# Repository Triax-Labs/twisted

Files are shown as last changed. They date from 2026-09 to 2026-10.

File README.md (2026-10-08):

<p align="center">
  
</p>
<h1 align="center">Twisted</h1>

Twisted is a tiny (14x32mm to be precise) ESP32-S3 based platform, which has dual Xtensa LX7 cores, 4Mb of flash, 2Mb of PSRAM, 512Kb of SRAM as well as BLE and WiFi on board, paired with an [0.42" IPS LCD](https://www.buydisplay.com/0-42-inch-mini-color-tft-lcd-display-module-96x54-ips-st7735), a keypad, a Neopixel and built-in battery management with USB OTG.




pcb layer by layer view

There is one more thing, the platform is extendable! It features a 20 pin 1.27mm expansion header which allows you of attaching other boards that add extra features, giving _Twisted_ a reason for its name.

We currently have three expansion boards for Twisted...

## Twisted Listen

An audio codec based on ES8316, which provides a high performance DAC and ADC, the attachment comes with both a builtin microphone and amplifier for a loudspeaker, as well as a 3.5mm headphone jack (with microphone in.)




pcb layer by layer view

## Twisted Connect

A shield for the Twisted Bus that provides the functionality of an extra microcontroller, it adds on a CH585 MCU which comes with an interesting set of peripherals, NFC/RFID (with support for reading, writing and emulating tags,) both a USB High Speed and a USB Full Speed controller as well as a BLE / 2.4GHz modem.

Twisted Connect could be used for using the peripherals on the CH585 MCU alongside the ESP32-S3 on the main Twisted board or it could be used to deep sleep the ESP32-S3 to preserve power, since Twisted Connect could take over the bus, it can wake up the ESP32-S3 when a trigger happens (e.g. sensors over I2C or a BLE/USB packet.)




pcb layer by layer view

## Twisted Sense (WIP)

An attachment that provides a a suite of sensors and trackers (pressure, temperature, humidity, gyroscope, accelerometer, magnetometer and GPS/GNSS) aiming to help the device "feel" what happens around it.

## Production

Production could be done through [JLCPCB](https://jlcpcb.com)'s PCBA service.

Total _(estimated)_ costs for Twisted boards (does not include any of the extra shields):

| Item | Price | Qty | Where |
| ---- | ----- | --- | --- |
| PCB  | $7 | 5 Boards | [JLCPCB](https://jlcpcb.com) |
| PCBA | $100  | 5 Boards | [JLCPCB](https://jlcpcb.com) |

You will need to assemble one side of the board, the other side which has the display, a resistor and the keypad you will have to assemble it yourself, or let JLCPCB assemble it for you at a higher cost.

You will need the display to be sourced and assembled by yourself, this is where you can buy it:

- AliExpress: [listing](https://aliexpress.com/item/1005007804650049.html) / [listing](https://aliexpress.com/item/1005008528322628.html) / [listing](https://aliexpress.com/item/1005012246832580.html) / [listing](https://aliexpress.com/item/1005008885821582.html)
- [BuyDisplay](https://www.buydisplay.com/0-42-inch-mini-color-tft-lcd-display-module-96x54-ips-st7735)

If you decide to buy the display from a different supplier, make sure it comes with a 16 pin flex cable, it also has to follow this pinout:


Total _(estimated)_ costs for Twisted Listen boards:

| Item | Price | Qty | Where |
| ---- | ----- | --- | --- |
| PCB  | $7 | 5 Boards | [JLCPCB](https://jlcpcb.com) |
| PCBA | $60 | 5 Boards | [JLCPCB](https://jlcpcb.com) |

Total _(estimated)_ costs for a Twisted Connect boards:

| Item | Price | Qty | Where |
| ---- | ----- | --- | --- |
| PCB  | $7 | 5 Boards | [JLCPCB](https://jlcpcb.com) |
| PCBA | $80 | 5 Boards | [JLCPCB](https://jlcpcb.com) |

_Note that these tables don't include shipping charges._

Production files could be found in `/hardware/X/production`.

## GPIO Pins Mapping (Twisted Bus)

| GPIO | Strap | ADC | HWSPI | Remark | Exposed | On Twisted |
| :--: | :---: | :---: | :---: | --- | :---: | --- |
|  0 |  Yes  | | | Pull LOW to Enter BOOT | No | Boot Button |
|  1 |  No | ADC1 CH0 | | | Yes | Expansion Header  |
|  2 |  No | ADC1 CH1 | | | Yes | Expansion Header  |
|  3 |  Yes  | ADC1 CH2 | | Pull LOW to Use An External Debugger Instead of USB | Yes | Expansion Header  |
|  4 |  No | ADC1 CH3 | | | Yes | Expansion Header  |
|  5 |  No | ADC1 CH4 | | | Yes | Expansion Header  |
|  6 |  No | ADC1 CH5 | | | Yes | Expansion Header  |
|  7 |  No | ADC1 CH6 | | | Yes | Expansion Header  |
|  8 |  No | ADC1 CH7 | | | Yes | Expansion Header  |
|  9 |  No | ADC1 CH8 | Hold  | | Yes | Expansion Header  |
|  10  |  No | ADC1 CH9 |  CS | | Yes | Expansion Header  |
|  11  |  No | ADC2 CH0 | MOSI  | | Yes | Expansion Header  |
|  12  |  No | ADC2 CH1 |  SCK  | | Yes | Expansion Header  |
|  13  |  No | ADC2 CH2 | MISO  | | Yes | Expansion Header  |
|  14  |  No | ADC2 CH3 |  WP | | Yes | Expansion Header  |
|  15  |  No | ADC2 CH4 | | | Yes | Expansion Header  |
|  16  |  No | ADC2 CH5 | | | Yes | Expansion Header  |
|  17  |  No | ADC2 CH6 | | | Yes | Expansion Header  |
|  18  |  No | ADC2 CH7 | | | No | Keypad: INT |
|  19  |  Yes  | ADC2 CH8 | | USB D- | Yes | USB Port |
|  20  |  Yes  | ADC2 CH9 | | USB D+ | Yes | USB Port |
|  21  |  No | | | | No | Neopixel: DIN |
|  26  |  Yes  | | | Used for QSPI Flash/PSRAM | No | Unused |
|  27  |  Yes  | | | Used for QSPI Flash/PSRAM | No | Unused |
|  28  |  Yes  | | | Used for QSPI Flash/PSRAM | No | Unused |
|  29  |  Yes  | | | Used for QSPI Flash/PSRAM | No | Unused |
|  30  |  Yes  | | | Used for QSPI Flash/PSRAM | No | Unused |
|  31  |  Yes  | | | Used for QSPI Flash/PSRAM | No | Unused |
|  32  |  Yes  | | | Used for QSPI Flash/PSRAM | No | Unused |
|  33  | Maybe | | | Straps for Chips w/ Octal-SPI PSRAM | No | LCD: RST |
|  34  | Maybe | | | Straps for Chips w/ Octal-SPI PSRAM | No | LCD: SCK |
|  35  | Maybe | | | Straps for Chips w/ Octal-SPI PSRAM | No | LCD: CS |
|  36  | Maybe | | | Straps for Chips w/ Octal-SPI PSRAM | No | LCD: MOSI |
|  37  | Maybe | | | Straps for Chips w/ Octal-SPI PSRAM | No | LCD: BKL |
|  38  |  No | | | | No | Unused |
|  39  |  No | | | | No | Keypad: RST |
|  40  |  No | | | | No | Unused |
|  41  |  No | | | | Through Testpoint | Internal I2C: SDA |
|  42  |  No | | | | Through Testpoint | Internal I2C: SDA |
|  43  |  No | | | Default UART: TX | Through Testpoint | Unused |
|  44  |  No | | | Default UART: RX | Through Testpoint | Unused |
|  45  |  Yes  | | | | No | Unused |
|  46  |  Yes  | | | | No | Unused |
|  47  |  No | | | | No | LCD: DC |
|  48  |  No | | | | No | BMS: INT |

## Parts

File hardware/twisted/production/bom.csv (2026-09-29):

Designator | Footprint | Quantity | Value | LCSC Part #
C1, C10_2, C2, C4, C5, C7, C8, C9 | C0402 | 8 | CL05A475MP5NRNC | C23733
C10, C11 | C0402 | 2 | CL05C100JB5NNNC | C32949
C12, C16 | C0402 | 2 | CL05A105KA5NQNC | C52923
C13, C14, C15, C17, C18, C3 | C0402 | 6 | CL05B104KO5NNNC | C1525
C19 | C0402 | 1 | CC0402KRX7R7BB104 | C60474
C6 | C0603 | 1 | CL10B473KB8NNNC | C1622
J1 | PinSocket_1x02_P1.27mm_Vertical | 1 | battery connector
L1 | L0603 | 1 | APH160808C1R0MX02 | C54123751
L2 | ANT-SMD_L3.2-W1.6 | 1 | KH-3216-A27 | C504001
LCD1 | 0.42-ST7735-Bent | 1 | ~
LED2 | LED-SMD_4P-L1.5-W1.5 | 1 | DY-S1515065/RGBC/6805-5T | C524053
R1, R2 | R0402 | 2 | 0402WGF5601TCE | C25908
R4 | R0402 | 1 | 0402WGF1001TCE | C11702
R5 | R0402 | 1 | 0402WGF499JTCE | C25120
SW1, SW2, SW3, SW4, SW5, SW6, SW7 | SW-SMD_L3.9-W3.0-P4.45 | 7 | TS-1088-AR02016 | C720477
TP1 | TinyTestPoint | 1 | BAT_STAT
TP10 | 2xTinyTestPoint | 1 | GND
TP2 | TinyTestPoint | 1 | SDA
TP3 | TinyTestPoint | 1 | SCL
TP4 | 2xTinyTestPoint | 1 | RESET
TP5 | 2xTinyTestPoint | 1 | UART_TX
TP6 | 2xTinyTestPoint | 1 | UART_RX
TP7 | 2xTinyTestPoint | 1 | USB_D+
TP8 | 2xTinyTestPoint | 1 | USB_D-
TP9 | 2xTinyTestPoint | 1 | VBUS
U1 | WQFN-18_L3.0-W2.5-P0.40-TL | 1 | BQ25628RYKR | C6055599
U2 | DFN2510-10_L2.5-W1.0-P0.50-BL | 1 | H5VU25UC | C20615800
U3 | CONN-SMD_20P-P1.27_KINGHELM_KH-1.27FH-2X10P-H4.3-SMT | 1 | KH-1.27FH-2X10P-H4.3-SMT | C2938399
U4 | DFN-4_L1.0-W1.0-P0.65-BL-EP | 1 | LW5233N11E | C20630430
U5 | UQFN-16_L2.6-W1.8-P0.40-BL | 1 | FXL6408UMX | C457770
U6 | QFN-56_L7.0-W7.0-P0.40-BL-EP5.7 | 1 | ESP32-S3FH4R2 | C3013940
USBC1 | USB-C_SMD-TYPE-C-31-M-12_1 | 1 | TYPE-C-31-M-12 | C165948
X1 | CRYSTAL-SMD_4P-L1.6-W1.2-BL | 1 | SX16Y040000B71T001 | C20623634

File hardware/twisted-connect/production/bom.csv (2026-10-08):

Designator | Footprint | Quantity | Value | LCSC Part #
ANT1 | Twisted-NFC-Antenna | 1 | 13.56MHz Chamfered 8T
C1, C2 | C0402 | 2 | 0402CG101J500NT | C1546
C10, C11 | C0402 | 2 | 0402B151K500NT | C1527
C12, C14 | C0402 | 2 | CL05A225MQ5NSNC | C12530
C13, C15, C4 | C0402 | 3 | CL05B104KO5NNNC | C1525
C16, C17 | C0603 | 2 | CL10A225KO8NNNC | C23630
C3, C5 | C0402 | 2 | CL05B103KB5NNNC | C15195
C6, C7 | C0402 | 2 | 0402CG220J500NT | C1555
C8, C9 | C0402 | 2 | 0402CG300J500NT | C1570
FPC1 | FPC-SMD_31P-P0.60_A03FC-S31FMA-H10 | 1 | A03FC-S31FMA-H10 | C42447807
H1, H2 | HDR-SMD_20P-P1.27-V-M-R2-C10-S1.27-LS5.5-1 | 2 | Double row of needle2*10 1.27mm | C59981
L1 | L0603 | 1 | CBMF1608T100K | C92982
R1 | R0402 | 1 | 0402WGF1001TCE | C11702
R10, R11, R5, R6, R7, R8, R9 | R0402 | 7 | 0402WGF5101TCE | C25905
R2 | R0402 | 1 | 0402WGF2001TCE | C4109
R3, R4 | R0402 | 2 | 0402WGF100KTCE | C25086
SW1, SW2 | SW-SMD_2P-TS24CA | 2 | TS24CA | C393942
U1, U9 | CONN-SMD_20P-P1.27_KINGHELM_KH-1.27FH-2X10P-H4.3-SMT | 2 | KH-1.27FH-2X10P-H4.3-SMT | C2938399
U10, U4, U5 | IPEX-SMD_BWIPX-1-001E | 3 | BWU.FL-IPEX1 | C5137195
U2, U3 | IND-SMD_L1.8-W1.3 | 2 | MLW1608RF-1R0MT | C2844624
U6 | QFN-48_L5.0-W5.0-P0.35-TL-EP3.7-1 | 1 | CH585M_C42381469 | C42381469
USBC1 | USB-C_SMD-TYPE-C-31-M-12_1 | 1 | TYPE-C-31-M-12 | C165948
X1 | CRYSTAL-SMD_2P-L2.0-W1.2 | 1 | XKHEL89CGI-112YLC-32.768K | C7500573
X2 | CRYSTAL-SMD_4P-L1.6-W1.2-BL | 1 | SX0B32.000F1210F30 | C7301923

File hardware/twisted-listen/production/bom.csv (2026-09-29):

Designator | Footprint | Quantity | Value | LCSC Part #
AUDIO1 | AUDIO-SMD_PJ-393-7A | 1 | PJ-393-7A | C128990
C1, C16, C17, C33, C4, C6, C7 | C0402 | 7 | CL05A105KA5NQNC | C52923
C10, C19, C2, C20, C22, C24, C27, C28 | C0402 | 8 | CL05A106MP5NUNC_C315248 | C315248
C11, C12, C13, C18, C21, C23, C25, C26, C5, C8, C9 | C0402 | 11 | CC0402KRX7R7BB104 | C60474
C14, C15 | C0402 | 2 | 0402CG200J500NT | C1554
C3 | C0402 | 1 | CL05B103KB5NNNC | C15195
CN1 | CONN-SMD_2P-P1.00_SM02B-SRSS-TB-LF-SN | 1 | SM02B-SRSS-TB | C160402
H1 | HDR-SMD_20P-P1.27-V-M-R2-C10-S1.27-LS5.5-1 | 1 | Double row of needle2*10 1.27mm | C59981
L1, L2 | L0603 | 2 | BLM18PG121SN1D | C14709
MIC1 | MIC-SMD_4P-L2.8-W1.9-P1.84-TL | 1 | ZTS6216 | C481302
R1, R2 | R0402 | 2 | 0402WGF2001TCE | C4109
R10, R11 | R0402 | 2 | 0402WGF4701TCE | C25900
R3, R4 | R0402 | 2 | 0402WGF1002TCE | C25744
R5, R6, R7, R8, R9 | R0402 | 5 | 0402WGF330JTCE | C25105
TP1, TP2, TP3, TP4 | TinyTestPoint | 4 | TestPoint
U1 | DFN-8_L2.0-W2.0-P0.50-BL-EP1.5 | 1 | LPA2103AQVF | C42460075
U2 | X2SON-8_L1.4-W0.8-P0.50-BL | 1 | TCA9536DTMR | C3190167
U3 | WSON-6_L2.0-W2.0-P0.65-TL-EP | 1 | LP5910-1.8DRVR | C2867568
U4 | QFN-32_L4.0-W4.0-P0.40-BL-EP2.7 | 1 | ES8316 | C365735
U5 | CONN-SMD_20P-P1.27_KINGHELM_KH-1.27FH-2X10P-H4.3-SMT | 1 | KH-1.27FH-2X10P-H4.3-SMT | C2938399

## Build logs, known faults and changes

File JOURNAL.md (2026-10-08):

# Twisted? What's That?

In early April, 2026, I found about [this tiny IPS LCD](https://www.buydisplay.com/0-42-inch-mini-color-tft-lcd-display-module-96x54-ips-st7735) panel from AliExpress, it measured only 0.42" and I felt like I should make something using it.

picture showing one of those tiny 0.42" displays doing action

So I decided to build a tiny development board around it, nothing really came in mind best at the time other than the ESP32-S3, as it had WiFi, BLE, USB and two quite powerful Xtensa LX7 cores with vector insturctions. I felt like it could serve as a powerful base that would be easily extended with other "shields" later down the line.

So I designed a tiny board around the ESP32-S3FN4R2 which has both the processor and extra memory in package, of course alongside that tiny display.

picture highlights PCB outline as well as the various layers

The board I designed at the time was made around parts I was able of finding locally, so I was quite limited by my parts selection.

At the end I finished the board and called it "Foton" as a code name, thought nothing of it and shared it online to the organisation's [Instagram profile.](https://www.instagram.com/p/DWvD35siBwf)

And then... nothing. It was left to dust, similar to a bunch of other projects, the reason behind leaving it behind was because of lack of funding for side projects.

Before I quit the project I had started working on a DAC/ADC shield for the thing based on the ES8388 codec, it was never completed as I had already moved onto other, slightly more yielding projects.



It was a headache, just thinking about a budget for such a project, given that customs are calculated randomly here in Egypt and often overshot due to ordering the minimum amount from JLCPCB, which is 5 boards, it makes them think that we are some kind of a reseller.

Foton sat for a good while like this, until early August when I decided to revisit the project and maybe shine new a beam onto it.

When I opened the design files, I realized the sad state of the schematic, turned out I had a different mindset four months back. I also had made some questionable routing decisions.

picture showing the current state of the schematic

I also realized that due to lack of space, which was cased by the size of the components I had used (limited by the local market), I decided to ditch battery management off board and instead leave it to an external shield.

Anyways, I decided to do a few things to Foton, so here is the plan.

- Foton becomes "Twisted". We decided to give it a rebrand under our open-source hardware organization, [Triax-Labs](https://github.com/Triax-Labs).
- Twisted should be a radically different design built around the outlines that the original prototype provided.
- Bring back the missing important traits like battery management (maybe with USB-OTG) and a wireless antenna that is built-in.
- Introduce more add-on/shield boards.

The idea behind Twisted is that it should be completely expandable using its bottom row of pin headers (02x10 pin, 1.27mm pitch.)

We are taking lots of inspiration from M5Stack's boards.

_We also need to find a small LiPo battery to use alongside the finished product._

---

# Starting from a Blank Slate

First, before doing anything we must get rid of all the existing connections and components as we are going to select everything again later.




All components that are going to change were removed, the schematic was cleaned up too.

I also have picked an antenna (`KH-3216-A27`)! It took a good while of research and lots of scrolling in `fcc.id`.

The ESP32-S3FH4R2 was kept in place, alongside its crystal. Connectors were also left as I'm using the exact outline as the original prototype.

## Picking a Battery Charger

Now, before I start wiring anything, a battery charger circuit must be put in place as the entire schematic should be put around it.

In the past I had made a long list of tiny charging ICs that I could later use.




However, this list didn't include a charger that had the requirements of my exact use case.

These requirements are: **NVDC power path**, **USB-OTG** boosting and a documented **I2C interface** as long as a package that is both tiny and **economically assembled at JLCPCB**.

After a good day of searching on JLCPCB's parts list, I came out with two candidates, `BQ2562xR` and the Chinese `BCT24157`.

Now the `BCT24157` comes at a really cheap price even for low quantities, however it comes in a BGA package which might be a bit expensive to assemble.
On the other hand the TI part `BQ2562xR` comes in a weird QFN-based package, but at an _expensive_ retail price per unit.



Choosing the `BCT24157` is quite risky, as its documentation quite lacks a lot of crucial information, as well as being a BGA package it could've ended in paying much more in PCBA.

I ended up picking the `BQ25628R`, as it comes with a less aggressive feature set than its sibling the `BQ25620R` which means a lower price, I wasn't going to use those features anyways.

## Boost Inductor Woes

A feature I always wanted to see on other platforms is USB-OTG, it allows people to use external peripherals when the device is being powered completely from battery, so users could use flash drives, keyboards and mice easily.

One issue though, USB-OTG requires a boost convert that in term needs a power inductor.

Usually power inductors are big and bulky, specifically for my application where every literal millimeter counts.

I'm was pretty certain that the isles of LCSC had something waiting for me, so I spent about 2 hours looking for an inductor that matches the requirements of the charger IC.

Eventually I found this inductor: `APH160808C1R0MX02` it is tiny (0603), has enough oomph and seems perfect for this exact application (which to be fair, did sound a bit suspicious to me at first.)



Now it all takes shape!

## Keypad and GPIO Expander

Twisted has a tiny set of 7 buttons on its front, serving as a keypad, 6 of those buttons are mapped for navigation and input, and the remaining one is connected to the BOOT pin of the MCU (which means it can be also used for input after the MCU boots up.)

The issue is, wiring 6 buttons to the MCU directly is quite wasteful and will result in less GPIOs exposed to the expansion header, that's why a GPIO expander was needed.

Finding a tiny GPIO expander that is cheap and has more than 4 GPIO slots was quite hard, I eventually found the `FXL6408UMX` which comes in a `1.8x2.6mm` QFN-like package.



## Voltage Regulation

The battery charger puts out `VBAT+` (3.3V - 4.2V) or `VBUS` (5V) on pin `VSYS` based on the charger presence. Thus, voltage regulation is a critical piece of the puzzle, the ESP32-S3 needs 3.3V in order to function, supplying `VSYS` directly would fry the hell out of it.

This one was easy though, as I had already used this part `LW5233N11E` many times before, it proves to be perfect for this application.

It is quite tiny measuring only `1x1mm`, as well as 500mA of output current (that's a lot compared to the size of the package.)


_Image of a different hardware project, the highlighted circles are the `LW5233N11E` voltage regulator in action._

## Meet Twisted!

Now the schematic is about complete:


And so is the board (skipping lots of routing pain.)




Say hi to Twisted :D

---

# Twisted Listen

Remember I've talked about an audio addon for Foton before it becomes Twisted?

I've revised that too, and it's now better than ever!




It is now based on the `ES8316` audio codec, which offers two ADC channels and two stereo DACs which allowed me to put a microphone on board as well as a small audio amplifier that could be used for adding a loudspeaker for Twisted.

---

# Twisted Connect

I have uploaded a new shield, Twisted Connect on October the 8th (a11f0e1c3315e99503966e0c169e91b8d9091f87)...





Twisted Connect is a shield for the Twisted Bus that provides the functionality of an extra microcontroller, it adds on a CH585 MCU which comes with an interesting set of peripherals, NFC/RFID (with support for reading, writing and emulating tags,) both a USB High Speed and a USB Full Speed controller as well as a BLE / 2.4GHz modem.

This shield could be used for either cooperative MCU communications (using best features from both boards) or it could be used to deep sleep the main MCU (the ESP32-S3) on the Twisted to preserve power.

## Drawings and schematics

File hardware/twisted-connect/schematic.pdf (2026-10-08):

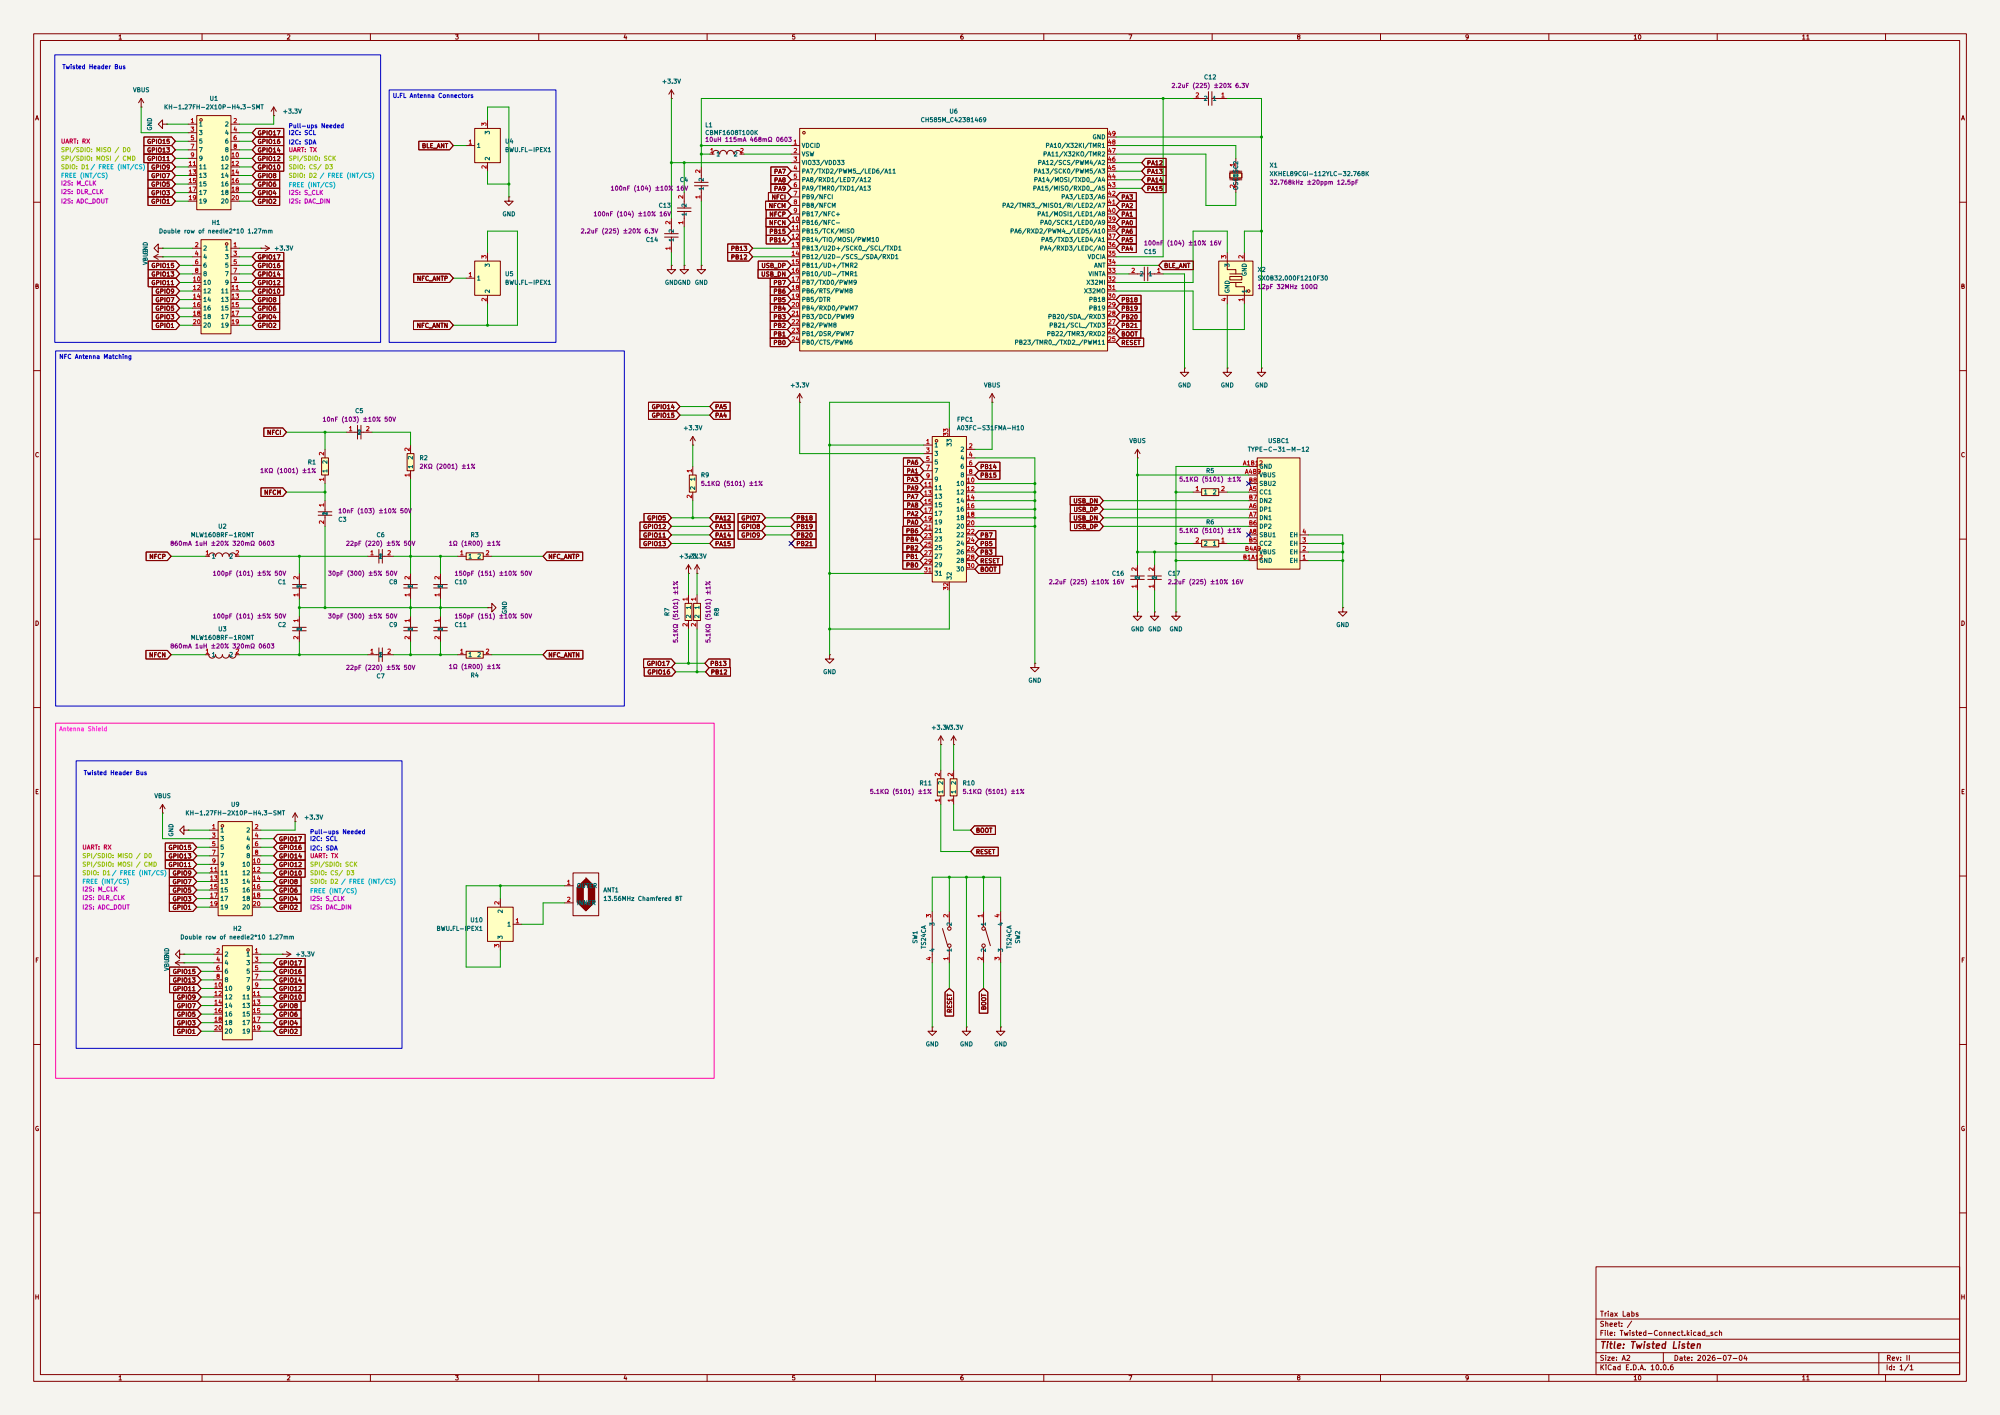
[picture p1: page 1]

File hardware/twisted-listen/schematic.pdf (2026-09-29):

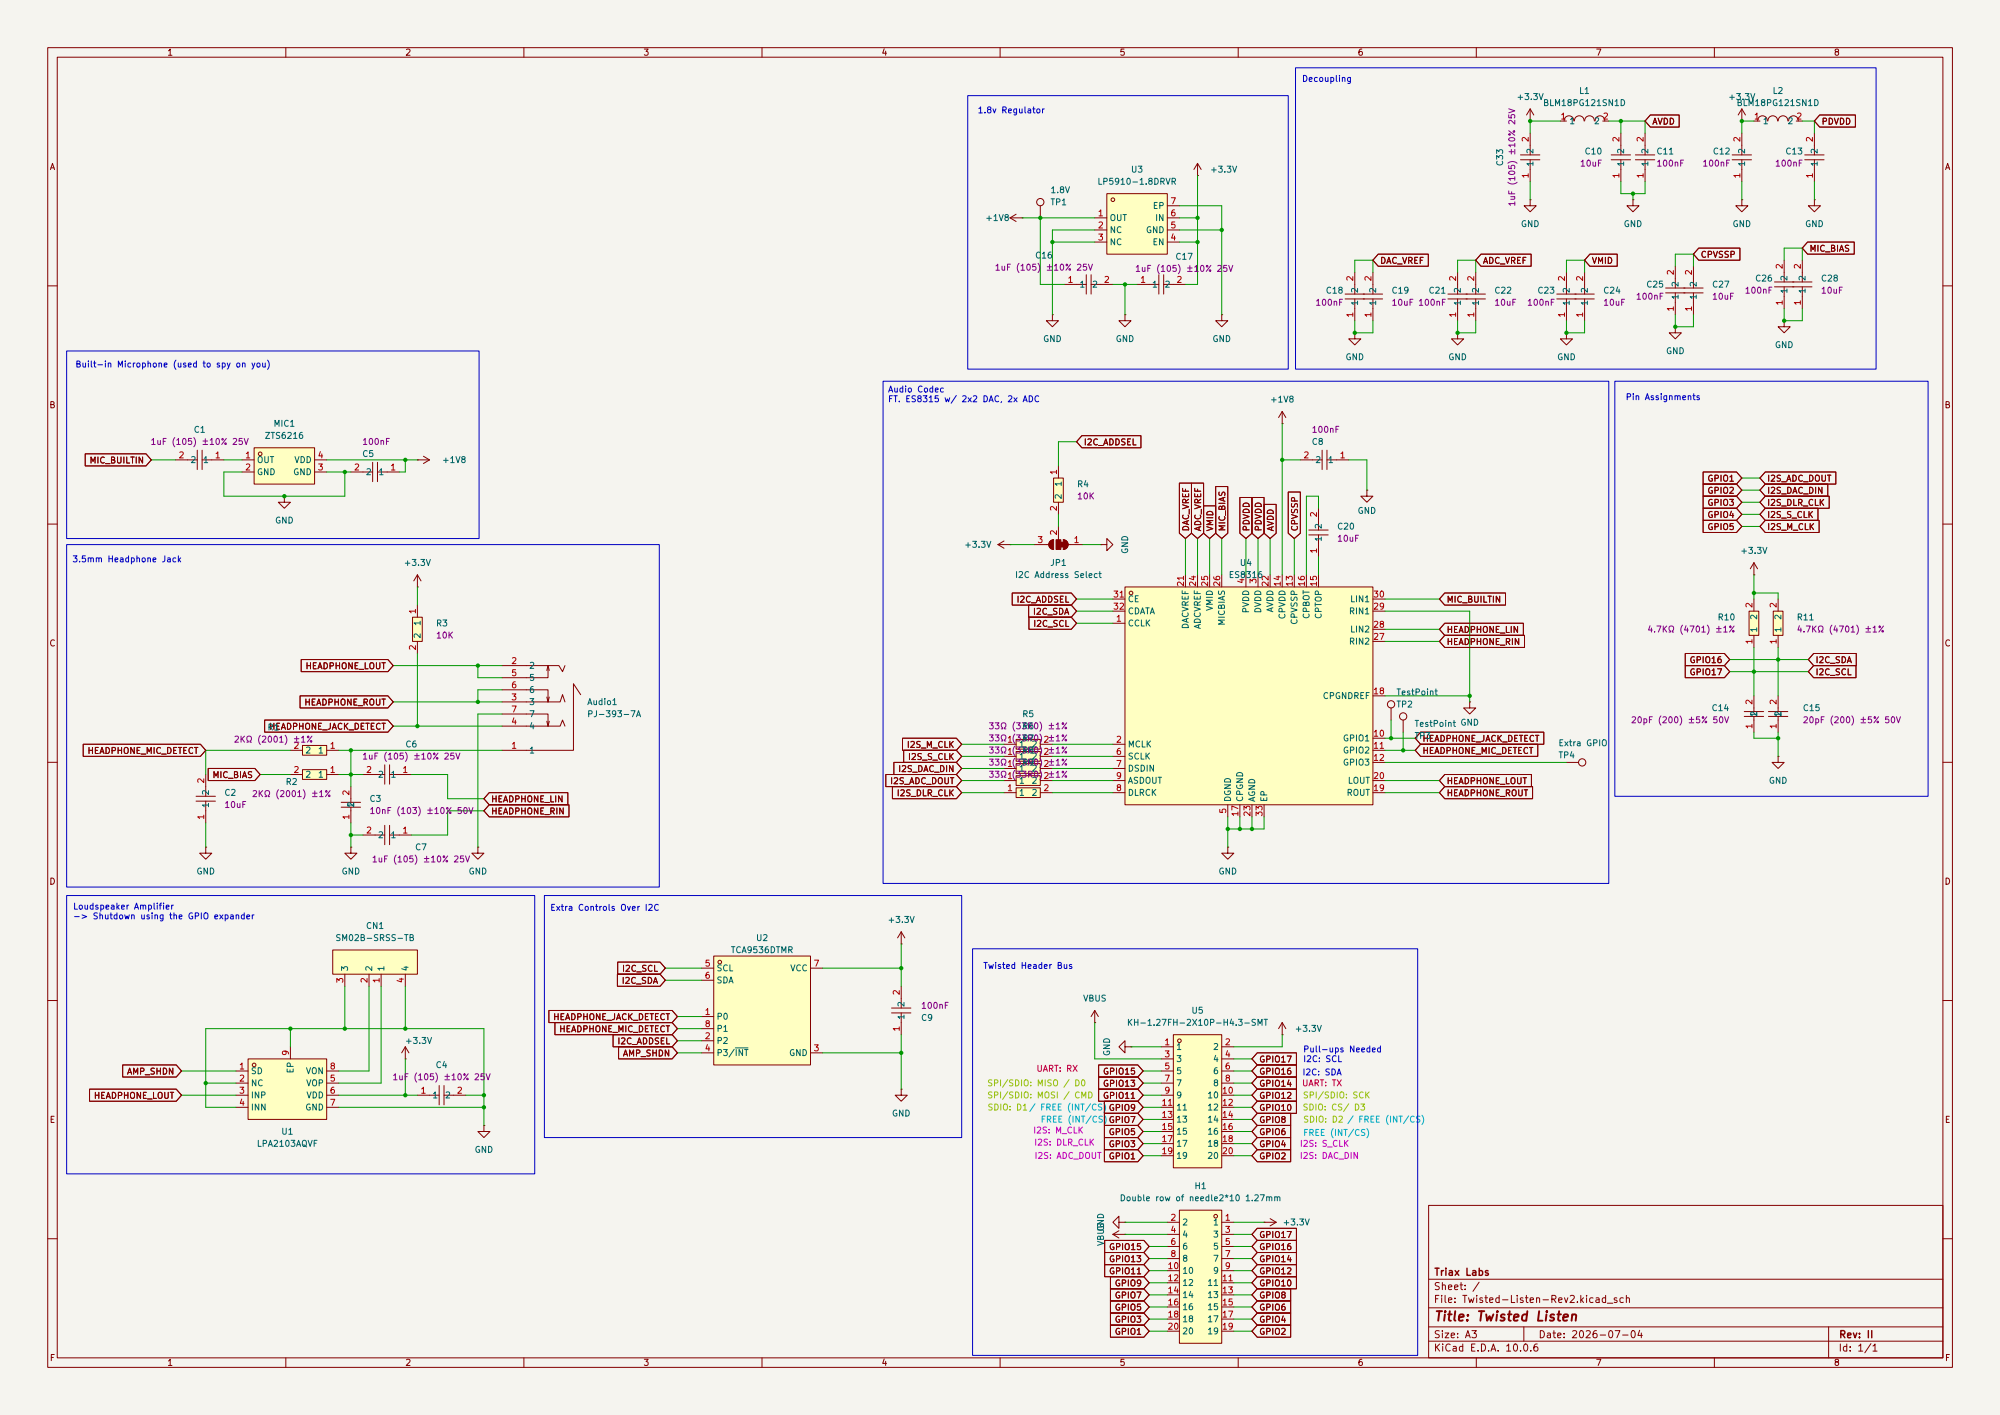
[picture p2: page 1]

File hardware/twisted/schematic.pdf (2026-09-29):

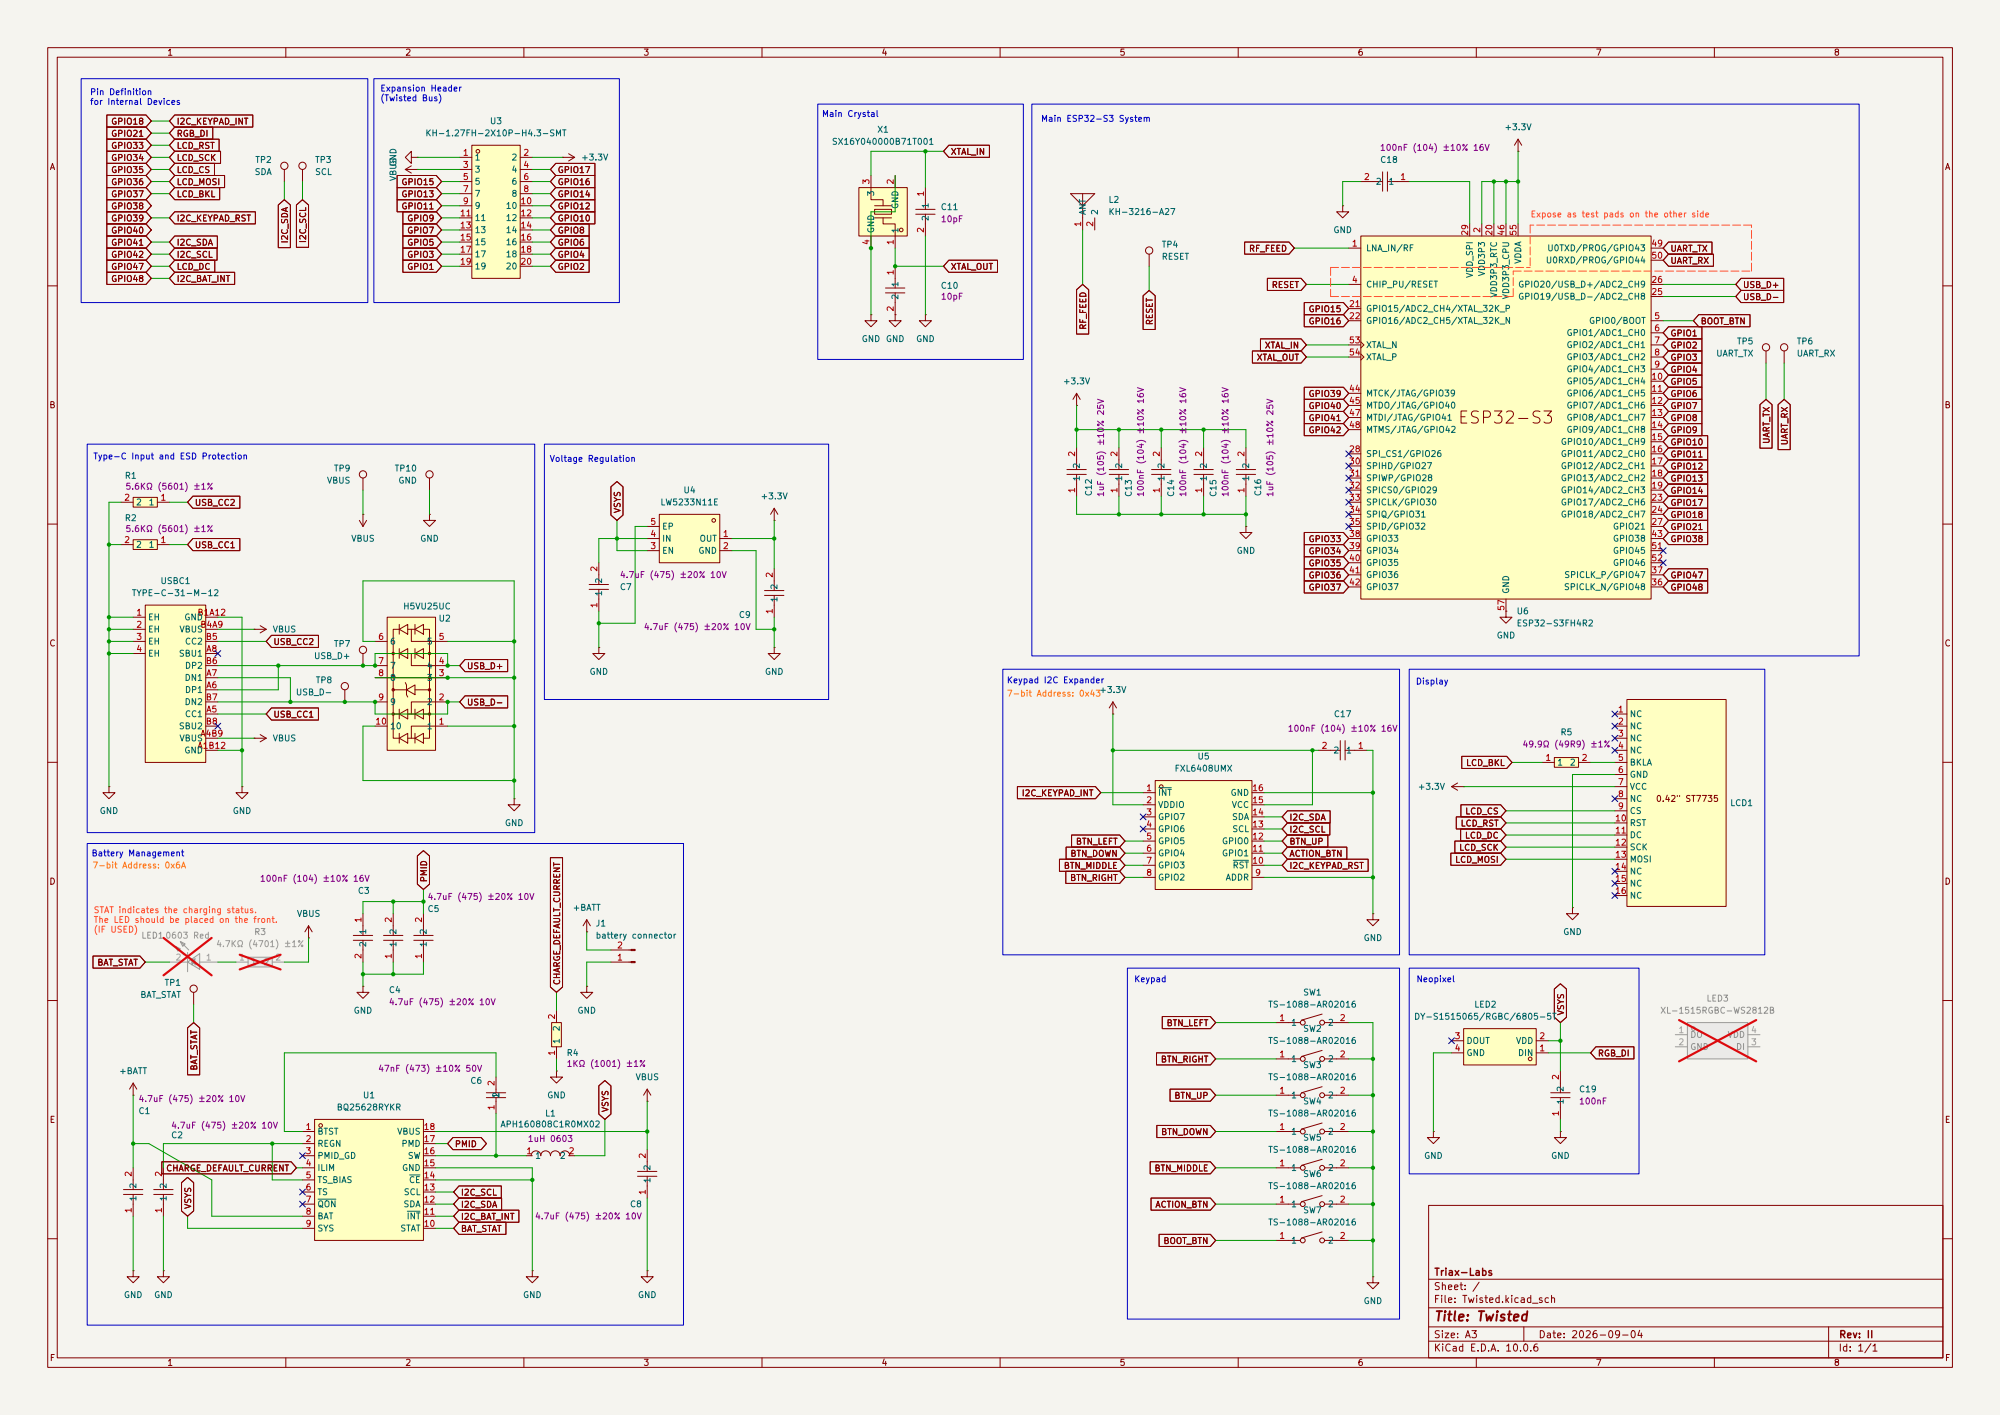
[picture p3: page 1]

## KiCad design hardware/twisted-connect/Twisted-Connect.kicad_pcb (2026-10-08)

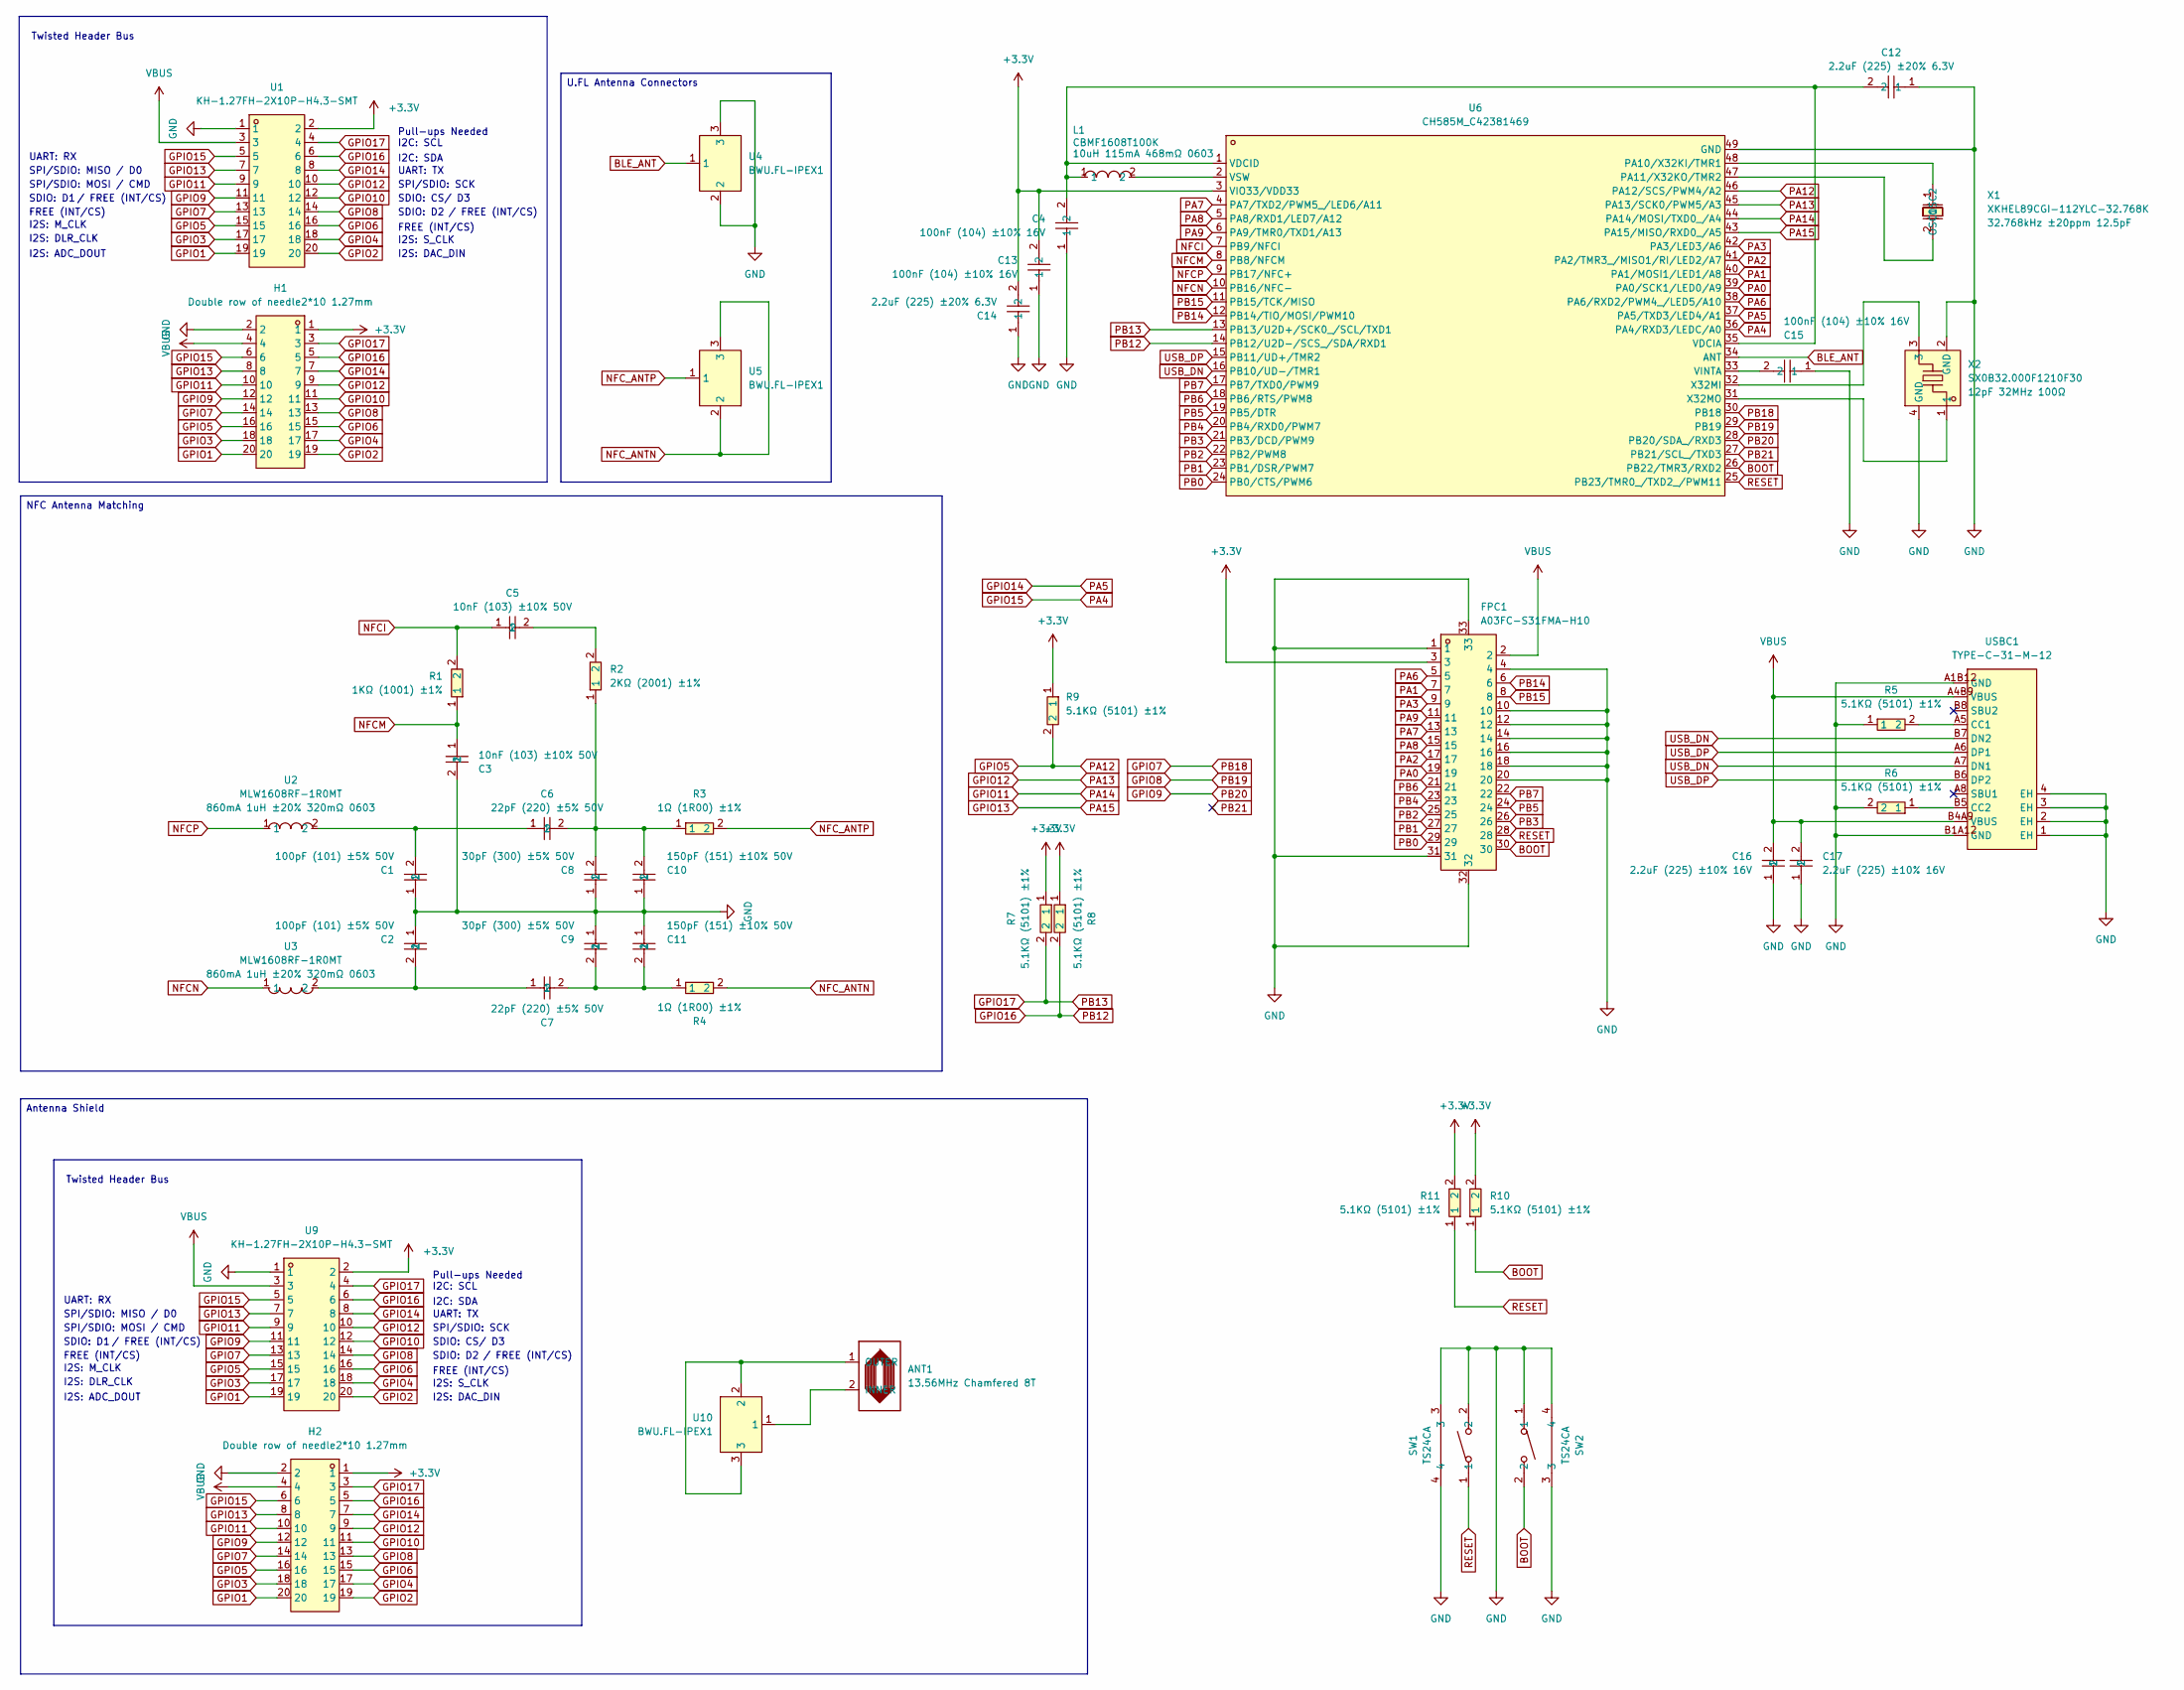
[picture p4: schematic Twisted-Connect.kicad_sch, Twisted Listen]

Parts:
ANT1: 13.56MHz Chamfered 8T; Twisted-NFC-Antenna
C1, C2: 0402CG101J500NT; C0402; MPN 0402CG101J500NT; LCSC Part C1546
C3, C5: CL05B103KB5NNNC; C0402; MPN CL05B103KB5NNNC; LCSC Part C15195
C4, C13, C15: CL05B104KO5NNNC; C0402; MPN CL05B104KO5NNNC; LCSC Part C1525
C6, C7: 0402CG220J500NT; C0402; MPN 0402CG220J500NT; LCSC Part C1555
C8, C9: 0402CG300J500NT; C0402; MPN 0402CG300J500NT; LCSC Part C1570
C10, C11: 0402B151K500NT; C0402; MPN 0402B151K500NT; LCSC Part C1527
C12, C14: CL05A225MQ5NSNC; C0402; MPN CL05A225MQ5NSNC; LCSC Part C12530
C16, C17: CL10A225KO8NNNC; C0603; MPN CL10A225KO8NNNC; LCSC Part C23630
FPC1: A03FC-S31FMA-H10; FPC-SMD_31P-P0.60_A03FC-S31FMA-H10; MPN A03FC-S31FMA-H10; LCSC Part C42447807
H1, H2: Double row of needle2*10 1.27mm; HDR-SMD_20P-P1.27-V-M-R2-C10-S1.27-LS5.5-1; MPN 1.27-2*10P立贴针; LCSC Part C59981
L1: CBMF1608T100K; L0603; MPN CBMF1608T100K; LCSC Part C92982
R1: 0402WGF1001TCE; R0402; MPN 0402WGF1001TCE; LCSC Part C11702
R2: 0402WGF2001TCE; R0402; MPN 0402WGF2001TCE; LCSC Part C4109
R3, R4: 0402WGF100KTCE; R0402; MPN 0402WGF100KTCE; LCSC Part C25086
R5, R6, R7, R8, R9, R10, R11: 0402WGF5101TCE; R0402; MPN 0402WGF5101TCE; LCSC Part C25905
SW1, SW2: TS24CA; SW-SMD_2P-TS24CA; MPN TS24CA; LCSC Part C393942
U1, U9: KH-1.27FH-2X10P-H4.3-SMT; CONN-SMD_20P-P1.27_KINGHELM_KH-1.27FH-2X10P-H4.3-SMT; LCSC Part C2938399
U2, U3: MLW1608RF-1R0MT; IND-SMD_L1.8-W1.3; MPN MLW1608RF-1R0MT; LCSC Part C2844624
U4, U5, U10: BWU.FL-IPEX1; IPEX-SMD_BWIPX-1-001E; MPN BWU.FL-IPEX1; LCSC Part C5137195
U6: CH585M_C42381469; QFN-48_L5.0-W5.0-P0.35-TL-EP3.7-1; MPN CH585M; LCSC Part C42381469
USBC1: TYPE-C-31-M-12; USB-C_SMD-TYPE-C-31-M-12_1; MPN TYPE-C-31-M-12; LCSC Part C165948
X1: XKHEL89CGI-112YLC-32.768K; CRYSTAL-SMD_2P-L2.0-W1.2; MPN XKHEL89CGI-112YLC-32.768K; LCSC Part C7500573
X2: SX0B32.000F1210F30; CRYSTAL-SMD_4P-L1.6-W1.2-BL; MPN SX0B32.000F1210F30; LCSC Part C7301923

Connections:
+3.3V: C13.2, C14.2, FPC1.3, H1.1, H2.1, R7.1, R8.1, R9.1, R10.2, R11.2, U1.2, U6.3 (VIO33/VDD33), U9.2
BLE_ANT: U4.1, U6.34 (ANT)
BOOT: FPC1.30, R10.1, SW2.2, U6.26 (PB22/TMR3/RXD2)
GND: C1.1, C2.1, C3.2, C4.1, C8.1, C9.1, C10.1, C11.1, C12.1, C13.1, C14.1, C15.1, C16.1, C17.1, FPC1.1, FPC1.4, FPC1.10, FPC1.12, FPC1.14, FPC1.16, FPC1.18, FPC1.20, FPC1.31, FPC1.32, FPC1.33, H1.2, H2.2, R5.1, R6.2, SW1.2, SW1.3, SW1.4, SW2.1, SW2.3, SW2.4, U1.1, U4.2, U4.3, U6.49 (GND), U9.1, USBC1.1 (EH), USBC1.2 (EH), USBC1.3 (EH), USBC1.4 (EH), USBC1.A1B12 (GND), USBC1.B1A12 (GND), X2.2 (GND), X2.4 (GND)
GPIO1: H1.20, H2.20, U1.19, U9.19
GPIO2: H1.19, H2.19, U1.20, U9.20
GPIO3: H1.18, H2.18, U1.17, U9.17
GPIO4: H1.17, H2.17, U1.18, U9.18
GPIO5: H1.16, H2.16, R9.2, U1.15, U6.46 (PA12/SCS/PWM4/A2), U9.15
GPIO6: H1.15, H2.15, U1.16, U9.16
GPIO7: H1.14, H2.14, U1.13, U6.30 (PB18), U9.13
GPIO8: H1.13, H2.13, U1.14, U6.29 (PB19), U9.14
GPIO9: H1.12, H2.12, U1.11, U6.28 (PB20/SDA_/RXD3), U9.11
GPIO10: H1.11, H2.11, U1.12, U9.12
GPIO11: H1.10, H2.10, U1.9, U6.44 (PA14/MOSI/TXD0_/A4), U9.9
GPIO12: H1.9, H2.9, U1.10, U6.45 (PA13/SCK0/PWM5/A3), U9.10
GPIO13: H1.8, H2.8, U1.7, U6.43 (PA15/MISO/RXD0_/A5), U9.7
GPIO14: H1.7, H2.7, U1.8, U6.37 (PA5/TXD3/LED4/A1), U9.8
GPIO15: H1.6, H2.6, U1.5, U6.36 (PA4/RXD3/LEDC/A0), U9.5
GPIO16: H1.5, H2.5, R8.2, U1.6, U6.14 (PB12/U2D-/SCS_/SDA/RXD1), U9.6
GPIO17: H1.3, H2.3, R7.2, U1.4, U6.13 (PB13/U2D+/SCK0_/SCL/TXD1), U9.4
NFCI: C5.1, R1.2, U6.7 (PB9/NFCI)
NFCM: C3.1, R1.1, U6.8 (PB8/NFCM)
NFCN: U3.1, U6.10 (PB16/NFC-)
NFCP: U2.1, U6.9 (PB17/NFC+)
NFC_ANTN: R4.2, U5.2, U5.3
NFC_ANTP: R3.2, U5.1
unnamed: ANT1.2 (INNER), U10.1
unnamed: ANT1.1 (OUTER), U10.2, U10.3
unnamed: C1.2, C6.1, U2.2
unnamed: C2.2, C7.1, U3.2
unnamed: C5.2, R2.2
unnamed: C6.2, C8.2, C10.2, R2.1, R3.1
unnamed: C7.2, C9.2, C11.2, R4.1
unnamed: U6.48 (PA10/X32KI/TMR1), X1.1 (OSC1)
unnamed: U6.47 (PA11/X32KO/TMR2), X1.2 (OSC2)
unnamed: C4.2, C12.2, L1.1, U6.1 (VDCID), U6.35 (VDCIA)
unnamed: C15.2, U6.33 (VINTA)
unnamed: L1.2, U6.2 (VSW)
unnamed: U6.32 (X32MI), X2.3
unnamed: U6.31 (X32MO), X2.1
unnamed: R5.2, USBC1.A5 (CC1)
unnamed: R6.1, USBC1.B5 (CC2)
PA0: FPC1.19, U6.39 (PA0/SCK1/LED0/A9)
PA1: FPC1.7, U6.40 (PA1/MOSI1/LED1/A8)
PA2: FPC1.17, U6.41 (PA2/TMR3_/MISO1/RI/LED2/A7)
PA3: FPC1.9, U6.42 (PA3/LED3/A6)
PA6: FPC1.5, U6.38 (PA6/RXD2/PWM4_/LED5/A10)
PA7: FPC1.13, U6.4 (PA7/TXD2/PWM5_/LED6/A11)
PA8: FPC1.15, U6.5 (PA8/RXD1/LED7/A12)
PA9: FPC1.11, U6.6 (PA9/TMR0/TXD1/A13)
PB0: FPC1.29, U6.24 (PB0/CTS/PWM6)
PB1: FPC1.27, U6.23 (PB1/DSR/PWM7)
PB2: FPC1.25, U6.22 (PB2/PWM8)
PB3: FPC1.26, U6.21 (PB3/DCD/PWM9)
PB4: FPC1.23, U6.20 (PB4/RXD0/PWM7)
PB5: FPC1.24, U6.19 (PB5/DTR)
PB6: FPC1.21, U6.18 (PB6/RTS/PWM8)
PB7: FPC1.22, U6.17 (PB7/TXD0/PWM9)
PB14: FPC1.6, U6.12 (PB14/TIO/MOSI/PWM10)
PB15: FPC1.8, U6.11 (PB15/TCK/MISO)
PB21: U6.27 (PB21/SCL_/TXD3)
RESET: FPC1.28, R11.1, SW1.1, U6.25 (PB23/TMR0_/TXD2_/PWM11)
USB_DN: U6.16 (PB10/UD-/TMR1), USBC1.A7 (DN1), USBC1.B7 (DN2)
USB_DP: U6.15 (PB11/UD+/TMR2), USBC1.A6 (DP1), USBC1.B6 (DP2)
VBUS: C16.2, C17.2, FPC1.2, H1.4, H2.4, U1.3, U9.3, USBC1.A4B9 (VBUS), USBC1.B4A9 (VBUS)

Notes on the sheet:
SPI/SDIO: MOSI / CMD
FREE (INT/CS)
I2S: DLR_CLK
UART: TX
SDIO: D2
I2S: S_CLK
I2S: ADC_DOUT
Twisted Header Bus
SDIO: CS/ D3
UART: RX
/ FREE (INT/CS)
Pull-ups Needed I2C: SCL
SDIO: D1
SPI/SDIO: SCK
I2C: SDA
I2S: DAC_DIN
SPI/SDIO: MISO / D0
I2S: M_CLK
Antenna Shield
U.FL Antenna Connectors
NFC Antenna Matching

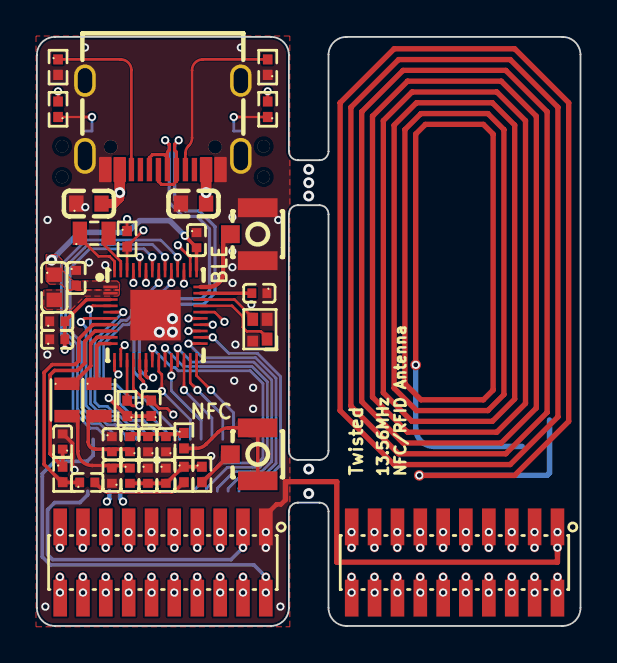
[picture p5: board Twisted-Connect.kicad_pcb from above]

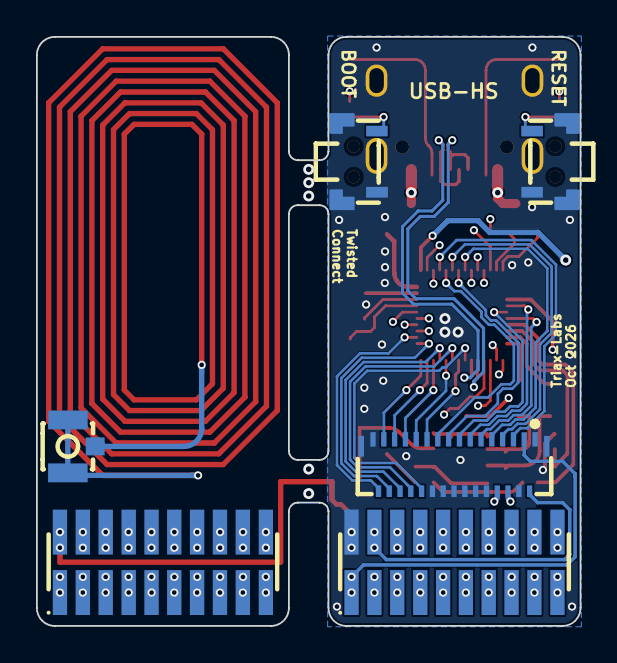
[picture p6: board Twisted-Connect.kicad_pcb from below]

Board: 4 copper layers, 30.2 x 32.7 mm, 46 parts (6 on the bottom side), 65 nets.

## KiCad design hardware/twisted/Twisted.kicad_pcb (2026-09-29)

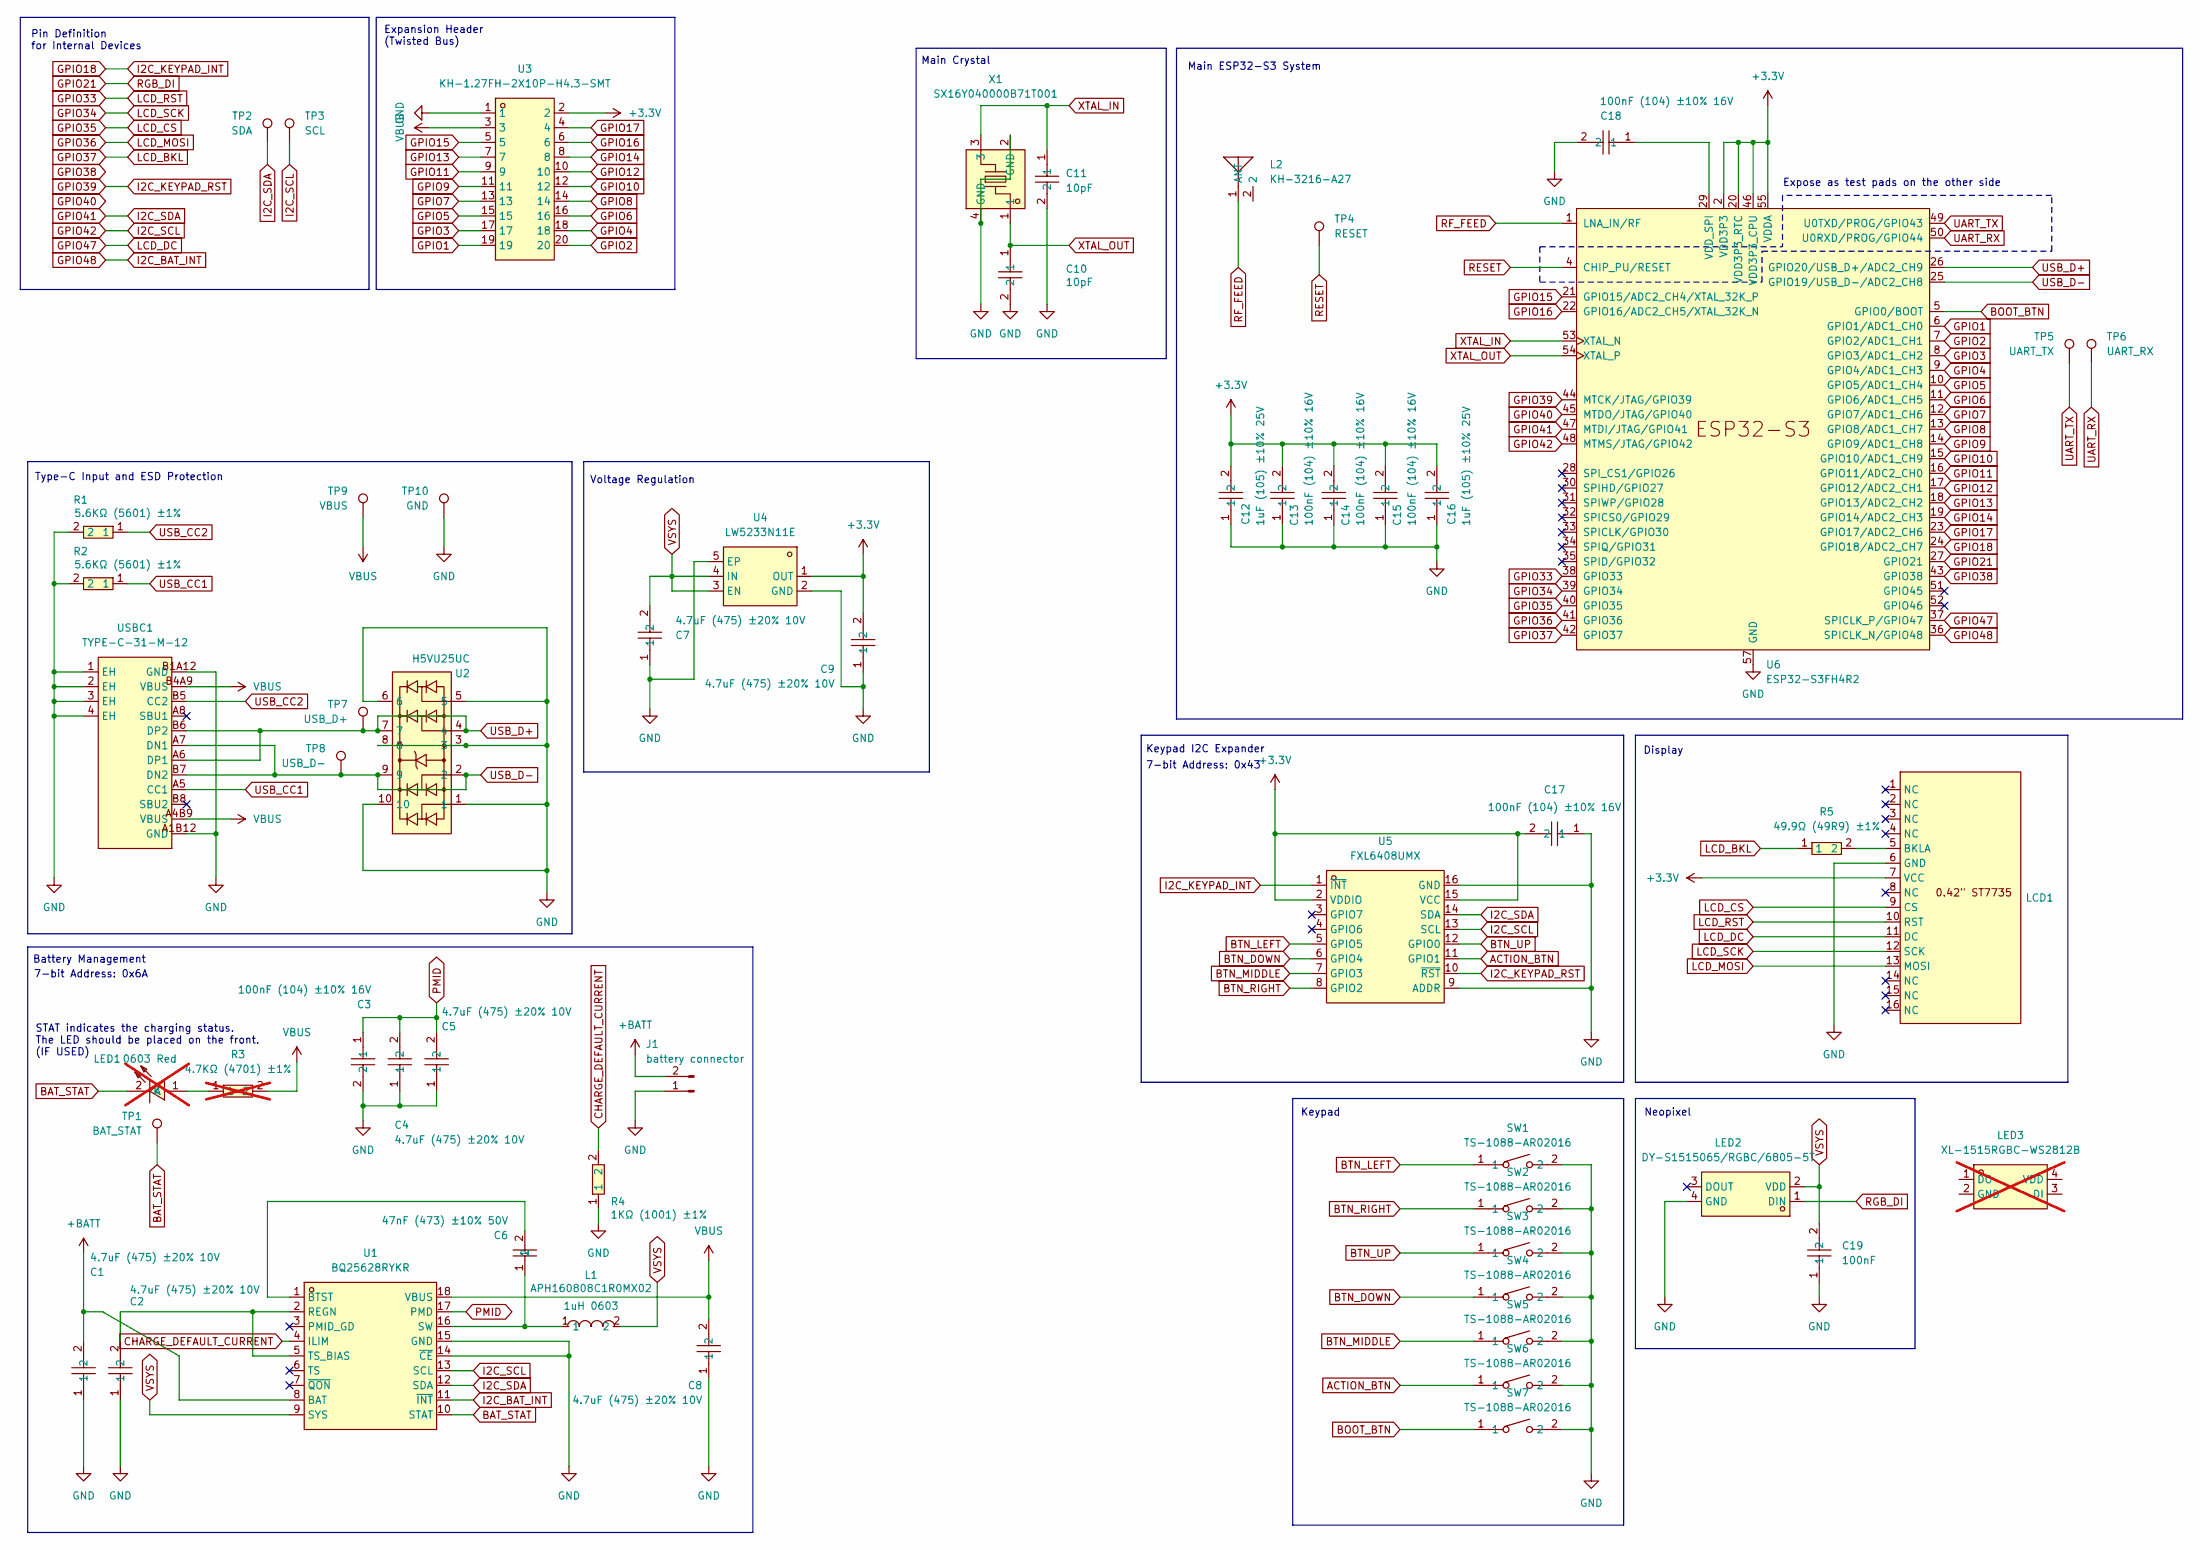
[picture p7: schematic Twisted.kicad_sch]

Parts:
C1, C2, C4, C5, C7, C8, C9: CL05A475MP5NRNC; C0402; MPN CL05A475MP5NRNC; LCSC Part C23733
C3, C13, C14, C15, C17, C18: CL05B104KO5NNNC; C0402; MPN CL05B104KO5NNNC; LCSC Part C1525
C6: CL10B473KB8NNNC; C0603; MPN CL10B473KB8NNNC; LCSC Part C1622
C10, C11: CL05C100JB5NNNC; C0402; LCSC Part C32949
C12, C16: CL05A105KA5NQNC; C0402; MPN CL05A105KA5NQNC; LCSC Part C52923
C19: CC0402KRX7R7BB104; C0402; LCSC Part C60474
J1: battery connector; PinSocket_1x02_P1.27mm_Vertical
L1: APH160808C1R0MX02; L0603; MPN APH160808C1R0MP01; LCSC Part C54123751
L2: KH-3216-A27; ANT-SMD_L3.2-W1.6; MPN KH-3216-A27; LCSC Part C504001
LCD1: 0.42-ST7735-Bent
LED1: KT-0603R; LED-SMD_L1.6-W0.8-R-RD; MPN KT-0603R; LCSC Part C2286; not fitted
LED2: DY-S1515065/RGBC/6805-5T; LED-SMD_4P-L1.5-W1.5; MPN DY-S1515065/RGBC/6805-5T; LCSC Part C524053
LED3: XL-1515RGBC-WS2812B; LED-ARRAY-SMD_4P-L1.6-W1.5-P0.85-TL; MPN XL-1515RGBC-2812B; LCSC Part C48586673; not fitted
R1, R2: 0402WGF5601TCE; R0402; MPN 0402WGF5601TCE; LCSC Part C25908
R3: 0402WGF4701TCE; R0402; MPN 0402WGF4701TCE; LCSC Part C25900; not fitted
R4: 0402WGF1001TCE; R0402; MPN 0402WGF1001TCE; LCSC Part C11702
R5: 0402WGF499JTCE; R0402; MPN 0402WGF499JTCE; LCSC Part C25120
SW1, SW2, SW3, SW4, SW5, SW6, SW7: TS-1088-AR02016; SW-SMD_L3.9-W3.0-P4.45; LCSC Part C720477
TP1: BAT_STAT; TinyTestPoint
TP2: SDA; TinyTestPoint
TP3: SCL; TinyTestPoint
TP4: RESET; 2xTinyTestPoint
TP5: UART_TX; 2xTinyTestPoint
TP6: UART_RX; 2xTinyTestPoint
TP7: USB_D+; 2xTinyTestPoint
TP8: USB_D-; 2xTinyTestPoint
TP9: VBUS; 2xTinyTestPoint
TP10: GND; 2xTinyTestPoint
U1: BQ25628RYKR; WQFN-18_L3.0-W2.5-P0.40-TL; MPN BQ25628RYKR; LCSC Part C6055599
U2: H5VU25UC; DFN2510-10_L2.5-W1.0-P0.50-BL; MPN H5VU25UC; LCSC Part C20615800
U3: KH-1.27FH-2X10P-H4.3-SMT; CONN-SMD_20P-P1.27_KINGHELM_KH-1.27FH-2X10P-H4.3-SMT; LCSC Part C2938399
U4: LW5233N11E; DFN-4_L1.0-W1.0-P0.65-BL-EP; MPN LW5233N11E; LCSC Part C20630430
U5: FXL6408UMX; UQFN-16_L2.6-W1.8-P0.40-BL; MPN FXL6408UMX; LCSC Part C457770
U6: ESP32-S3FH4R2; QFN-56_L7.0-W7.0-P0.40-BL-EP5.7; LCSC Part C3013940
USBC1: TYPE-C-31-M-12; USB-C_SMD-TYPE-C-31-M-12_1; LCSC Part C165948
X1: SX16Y040000B71T001; CRYSTAL-SMD_4P-L1.6-W1.2-BL; LCSC Part C20623634

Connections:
+BATT: C1.2, J1.2, U1.8 (BAT)
ACTION_BTN: SW6.1, U5.11 (GPIO1)
BAT_STAT: LED1.2 (K), TP1.1 (1_1), U1.10 (STAT)
BOOT_BTN: SW7.1, U6.5 (GPIO0/BOOT)
BTN_DOWN: SW4.1, U5.6 (GPIO4)
BTN_LEFT: SW1.1, U5.5 (GPIO5)
BTN_MIDDLE: SW5.1, U5.7 (GPIO3)
BTN_RIGHT: SW2.1, U5.8 (GPIO2)
BTN_UP: SW3.1, U5.12 (GPIO0)
CHARGE_DEFAULT_CURRENT: R4.2, U1.4 (ILIM)
GPIO1: U3.19, U6.6 (GPIO1/ADC1_CH0)
GPIO2: U3.20, U6.7 (GPIO2/ADC1_CH1)
GPIO3: U3.17, U6.8 (GPIO3/ADC1_CH2)
GPIO4: U3.18, U6.9 (GPIO4/ADC1_CH3)
GPIO5: U3.15, U6.10 (GPIO5/ADC1_CH4)
GPIO6: U3.16, U6.11 (GPIO6/ADC1_CH5)
GPIO7: U3.13, U6.12 (GPIO7/ADC1_CH6)
GPIO8: U3.14, U6.13 (GPIO8/ADC1_CH7)
GPIO9: U3.11, U6.14 (GPIO9/ADC1_CH8)
GPIO10: U3.12, U6.15 (GPIO10/ADC1_CH9)
GPIO11: U3.9, U6.16 (GPIO11/ADC2_CH0)
GPIO12: U3.10, U6.17 (GPIO12/ADC2_CH1)
GPIO13: U3.7, U6.18 (GPIO13/ADC2_CH2)
GPIO14: U3.8, U6.19 (GPIO14/ADC2_CH3)
GPIO15: U3.5, U6.21 (GPIO15/ADC2_CH4/XTAL_32K_P)
GPIO16: U3.6, U6.22 (GPIO16/ADC2_CH5/XTAL_32K_N)
GPIO17: U3.4, U6.23 (GPIO17/ADC2_CH6)
GPIO18: U5.1 (~INT), U6.24 (GPIO18/ADC2_CH7)
GPIO21: LED2.1 (DIN), U6.27 (GPIO21)
GPIO33: LCD1.10 (RST), U6.38 (GPIO33)
GPIO34: LCD1.12 (SCK), U6.39 (GPIO34)
GPIO35: LCD1.9 (CS), U6.40 (GPIO35)
GPIO36: LCD1.13 (MOSI), U6.41 (GPIO36)
GPIO37: R5.1, U6.42 (GPIO37)
GPIO38: U6.43 (GPIO38)
GPIO39: U5.10 (~RST), U6.44 (MTCK/JTAG/GPIO39)
GPIO40: U6.45 (MTDO/JTAG/GPIO40)
GPIO41: TP2.1 (1_1), U1.12 (SDA), U5.14 (SDA), U6.47 (MTDI/JTAG/GPIO41)
GPIO42: TP3.1 (1_1), U1.13 (SCL), U5.13 (SCL), U6.48 (MTMS/JTAG/GPIO42)
GPIO47: LCD1.11 (DC), U6.37 (SPICLK_P/GPIO47)
GPIO48: U1.11 (~INT), U6.36 (SPICLK_N/GPIO48)
unnamed: LCD1.5 (BKLA), R5.2
unnamed: LED1.1 (A), R3.1
unnamed: C6.2, U1.1 (BTST)
unnamed: C2.2, U1.2 (REGN), U1.5 (TS_BIAS)
unnamed: C6.1, L1.1, U1.16 (SW)
unnamed: C18.1, U6.29 (VDD_SPI)
PMID: C3.1, C4.2, C5.2, U1.17 (PMD)
RESET: TP4.1 (1_1), U6.4 (CHIP_PU/RESET)
RF_FEED: L2.1 (ANT_1), U6.1 (LNA_IN/RF)
UART_RX: TP6.1 (1_1), U6.50 (U0RXD/PROG/GPIO44)
UART_TX: TP5.1 (1_1), U6.49 (U0TXD/PROG/GPIO43)
USB_CC1: R2.1, USBC1.A5 (CC1)
USB_CC2: R1.1, USBC1.B5 (CC2)
USB_D+: TP7.1 (1_1), U2.4, U2.7, U6.26 (GPIO20/USB_D+/ADC2_CH9), USBC1.A6 (DP1), USBC1.B6 (DP2)
USB_D-: TP8.1 (1_1), U2.2, U2.9, U6.25 (GPIO19/USB_D-/ADC2_CH8), USBC1.A7 (DN1), USBC1.B7 (DN2)
VBUS: C8.2, R3.2, TP9.1 (1_1), U1.18 (VBUS), U3.3, USBC1.A4B9 (VBUS), USBC1.B4A9 (VBUS)
VSYS: C7.2, C19.2, L1.2, LED2.2 (VDD), U1.9 (SYS), U4.3 (EN), U4.4 (IN)
XTAL_IN: C11.1, U6.53 (XTAL_N), X1.3

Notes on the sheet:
Main ESP32-S3 System
Expose as test pads on the other side
Neopixel
Keypad I2C Expander
STAT indicates the charging status. The LED should be placed on the front. (IF USED)
Type-C Input and ESD Protection
Battery Management
Main Crystal
Display
Pin Definition for Internal Devices
Expansion Header (Twisted Bus)
Keypad
7-bit Address: 0x43
7-bit Address: 0x6A
Voltage Regulation

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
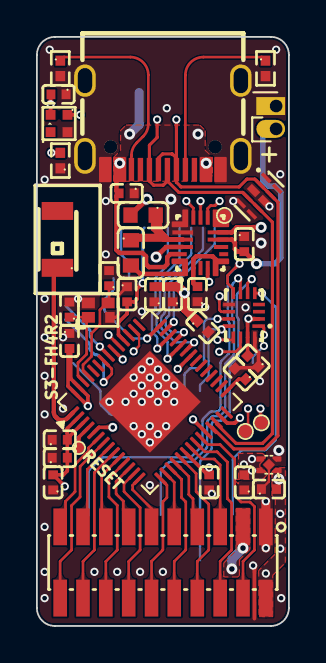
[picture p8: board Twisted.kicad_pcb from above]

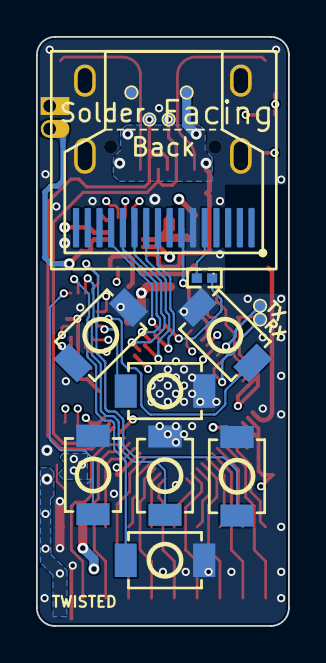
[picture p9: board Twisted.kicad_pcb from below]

Board: 4 copper layers, 14.0 x 32.7 mm, 54 parts (15 on the bottom side), 59 nets.

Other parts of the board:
C10#2: CL05C100JB5NNNC; C0402

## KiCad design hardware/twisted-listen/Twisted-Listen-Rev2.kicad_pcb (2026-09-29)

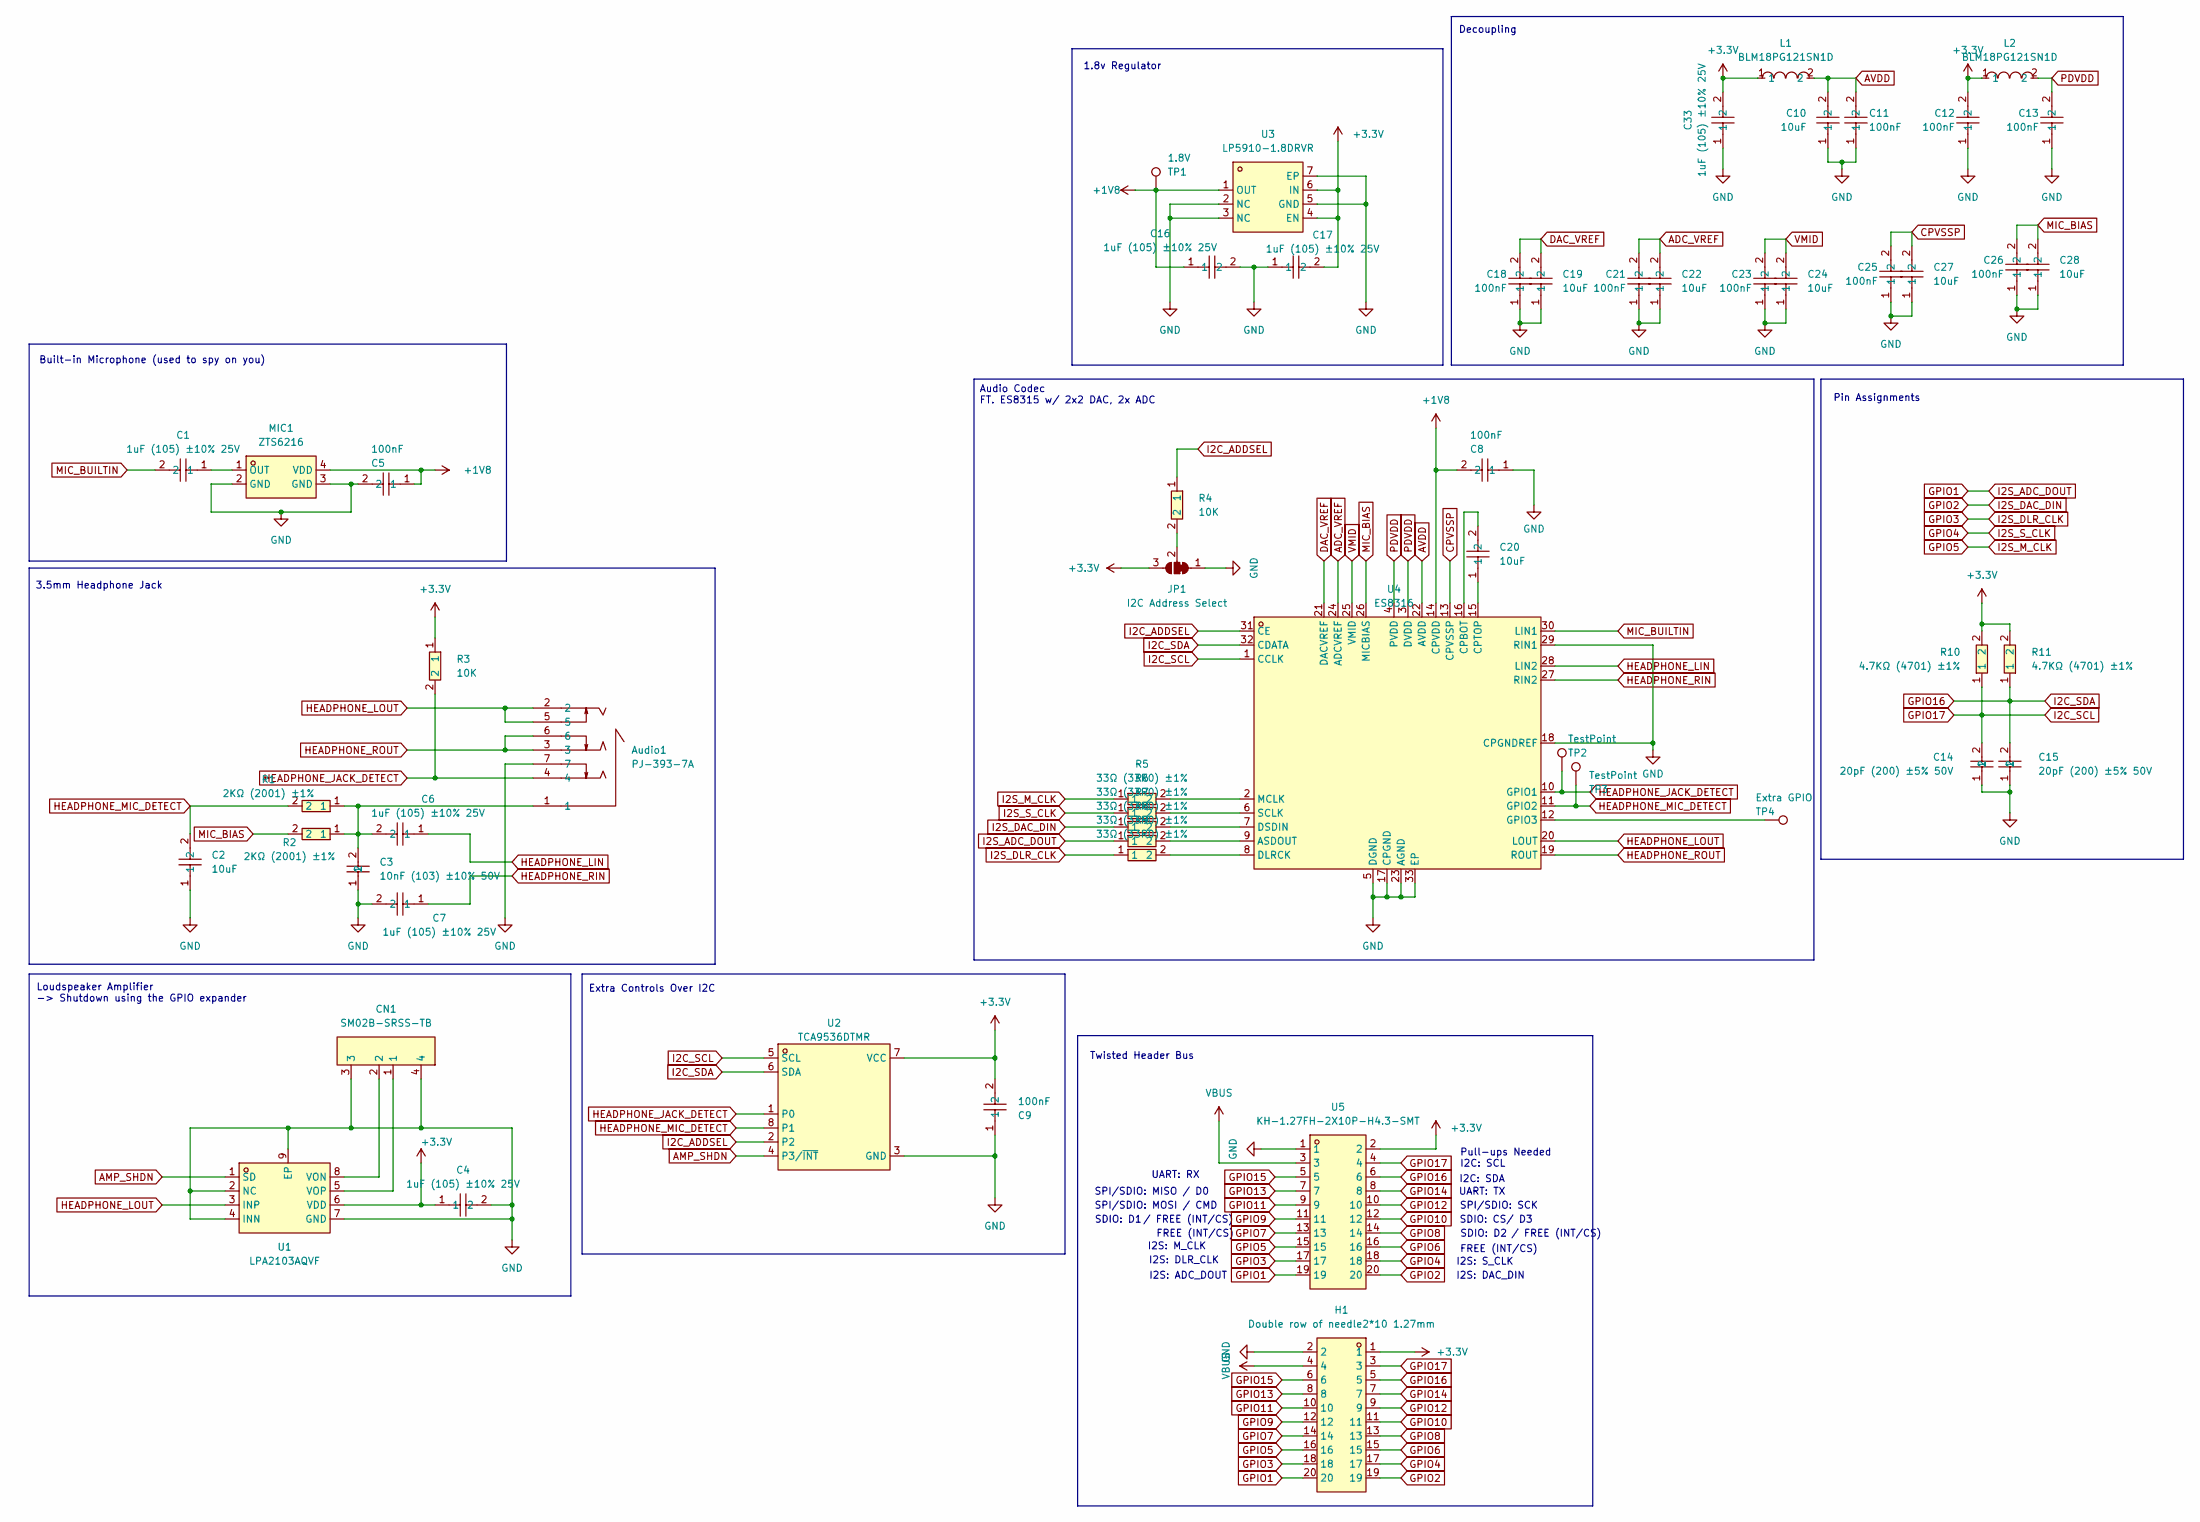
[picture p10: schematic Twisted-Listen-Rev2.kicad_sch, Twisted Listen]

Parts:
Audio1: PJ-393-7A; AUDIO-SMD_PJ-393-7A; MPN PJ-393-7A; LCSC Part C128990
C1, C4, C6, C7, C16, C17, C33: CL05A105KA5NQNC; C0402; MPN CL05A105KA5NQNC; LCSC Part C52923
C2, C10, C19, C20, C22, C24, C27, C28: CL05A106MP5NUNC_C315248; C0402; LCSC Part C315248
C3: CL05B103KB5NNNC; C0402; MPN CL05B103KB5NNNC; LCSC Part C15195
C5, C8, C9, C11, C12, C13, C18, C21, C23, C25, C26: CC0402KRX7R7BB104; C0402; LCSC Part C60474
C14, C15: 0402CG200J500NT; C0402; MPN 0402CG200J500NT; LCSC Part C1554
CN1: SM02B-SRSS-TB; CONN-SMD_2P-P1.00_SM02B-SRSS-TB-LF-SN; MPN SM02B-SRSS-TB(LF)(SN); LCSC Part C160402
H1: Double row of needle2*10 1.27mm; HDR-SMD_20P-P1.27-V-M-R2-C10-S1.27-LS5.5-1; MPN 1.27-2*10P立贴针; LCSC Part C59981
JP1: I2C Address Select; SolderJumper-3_P1.3mm_Bridged12_RoundedPad1.0x1.5mm
L1, L2: BLM18PG121SN1D; L0603; MPN BLM18PG121SN1D; LCSC Part C14709
MIC1: ZTS6216; MIC-SMD_4P-L2.8-W1.9-P1.84-TL; MPN ZTS6216; LCSC Part C481302
R1, R2: 0402WGF2001TCE; R0402; MPN 0402WGF2001TCE; LCSC Part C4109
R3, R4: 0402WGF1002TCE; R0402; LCSC Part C25744
R5, R6, R7, R8, R9: 0402WGF330JTCE; R0402; MPN 0402WGF330JTCE; LCSC Part C25105
R10, R11: 0402WGF4701TCE; R0402; MPN 0402WGF4701TCE; LCSC Part C25900
TP1: 1.8V; TinyTestPoint
TP2, TP3: TestPoint; TinyTestPoint
TP4: Extra GPIO; TinyTestPoint
U1: LPA2103AQVF; DFN-8_L2.0-W2.0-P0.50-BL-EP1.5; MPN LPA2103AQVF; LCSC Part C42460075
U2: TCA9536DTMR; X2SON-8_L1.4-W0.8-P0.50-BL; MPN TCA9536DTMR; LCSC Part C3190167
U3: LP5910-1.8DRVR; WSON-6_L2.0-W2.0-P0.65-TL-EP; MPN LP5910-1.8DRVR; LCSC Part C2867568
U4: ES8316; QFN-32_L4.0-W4.0-P0.40-BL-EP2.7; MPN ES8316; LCSC Part C365735
U5: KH-1.27FH-2X10P-H4.3-SMT; CONN-SMD_20P-P1.27_KINGHELM_KH-1.27FH-2X10P-H4.3-SMT; LCSC Part C2938399

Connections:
+1V8: C5.1, C8.2, C16.1, MIC1.4 (VDD), TP1.1 (1_1), U3.1 (OUT), U4.14 (CPVDD)
+3.3V: C4.1, C9.2, C12.2, C17.2, C33.2, H1.1, JP1.3 (B), L1.1, L2.1, R3.1, R10.2, R11.2, U1.6 (VDD), U2.7 (VCC), U3.4 (EN), U3.6 (IN), U5.2
ADC_VREF: C21.2, C22.2, U4.24 (ADCVREF)
AMP_SHDN: U1.1 (SD), U2.4 (P3/~INT)
AVDD: C10.2, C11.2, L1.2, U4.22 (AVDD)
CPVSSP: C25.2, C27.2, U4.13 (CPVSSP)
DAC_VREF: C18.2, C19.2, U4.21 (DACVREF)
GND: Audio1.7, C2.1, C3.1, C4.2, C5.2, C7.2, C8.1, C9.1, C10.1, C11.1, C12.1, C13.1, C14.1, C15.1, C16.2, C17.1, C18.1, C19.1, C21.1, C22.1, C23.1, C24.1, C25.1, C26.1, C27.1, C28.1, C33.1, CN1.3, CN1.4, H1.2, JP1.1 (A), MIC1.2 (GND), MIC1.3 (GND), U1.2 (NC), U1.4 (INN), U1.7 (GND), U1.9 (EP), U2.3 (GND), U3.2 (NC), U3.3 (NC), U3.5 (GND), U3.7 (EP), U4.5 (DGND), U4.17 (CPGND), U4.18 (CPGNDREF), U4.23 (AGND), U4.29 (RIN1), U4.33 (EP), U5.1
GPIO1: H1.20, R8.1, U5.19
GPIO2: H1.19, R7.1, U5.20
GPIO3: H1.18, R9.1, U5.17
GPIO4: H1.17, R6.1, U5.18
GPIO5: H1.16, R5.1, U5.15
GPIO6: H1.15, U5.16
GPIO7: H1.14, U5.13
GPIO8: H1.13, U5.14
GPIO9: H1.12, U5.11
GPIO10: H1.11, U5.12
GPIO11: H1.10, U5.9
GPIO12: H1.9, U5.10
GPIO13: H1.8, U5.7
GPIO14: H1.7, U5.8
GPIO15: H1.6, U5.5
GPIO16: C15.2, H1.5, R11.1, U2.6 (SDA), U4.32 (CDATA), U5.6
GPIO17: C14.2, H1.3, R10.1, U2.5 (SCL), U4.1 (CCLK), U5.4
HEADPHONE_JACK_DETECT: Audio1.4, R3.2, TP2.1 (1_1), U2.1 (P0), U4.10 (GPIO1)
HEADPHONE_LIN: C6.1, U4.28 (LIN2)
HEADPHONE_LOUT: Audio1.2, Audio1.5, U1.3 (INP), U4.20 (LOUT)
HEADPHONE_MIC_DETECT: C2.2, R1.2, TP3.1 (1_1), U2.8 (P1), U4.11 (GPIO2)
HEADPHONE_RIN: C7.1, U4.27 (RIN2)
HEADPHONE_ROUT: Audio1.3, Audio1.6, U4.19 (ROUT)
I2C_ADDSEL: R4.1, U2.2, U4.31 (CE)
MIC_BIAS: C26.2, C28.2, R2.2, U4.26 (MICBIAS)
MIC_BUILTIN: C1.2, U4.30 (LIN1)
unnamed: Audio1.1, C3.2, C6.2, R1.1, R2.1
unnamed: JP1.2 (C), R4.2
unnamed: C1.1, MIC1.1 (OUT)
unnamed: CN1.2, U1.8 (VON)
unnamed: CN1.1, U1.5 (VOP)
unnamed: R8.2, U4.9 (ASDOUT)
unnamed: C20.2, U4.16 (CPBOT)
unnamed: C20.1, U4.15 (CPTOP)
unnamed: R9.2, U4.8 (DLRCK)
unnamed: R7.2, U4.7 (DSDIN)
unnamed: TP4.1 (1_1), U4.12 (GPIO3)
unnamed: R5.2, U4.2 (MCLK)
unnamed: R6.2, U4.6 (SCLK)
PDVDD: C13.2, L2.2, U4.3 (DVDD), U4.4 (PVDD)
VBUS: H1.4, U5.3
VMID: C23.2, C24.2, U4.25 (VMID)

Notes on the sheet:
SPI/SDIO: MOSI / CMD
I2S: DLR_CLK
UART: TX
FREE (INT/CS)
1.8v Regulator
I2S: S_CLK
I2S: ADC_DOUT
Extra Controls Over I2C
Pin Assignments
UART: RX
Pull-ups Needed I2C: SCL
SDIO: D2
Built-in Microphone (used to spy on you)
SDIO: CS/ D3
SDIO: D1
/ FREE (INT/CS)
I2S: DAC_DIN
Loudspeaker Amplifier -> Shutdown using the GPIO expander
SPI/SDIO: MISO / D0
I2S: M_CLK
3.5mm Headphone Jack
Decoupling
Twisted Header Bus
SPI/SDIO: SCK
I2C: SDA
Audio Codec FT. ES8315 w/ 2x2 DAC, 2x ADC

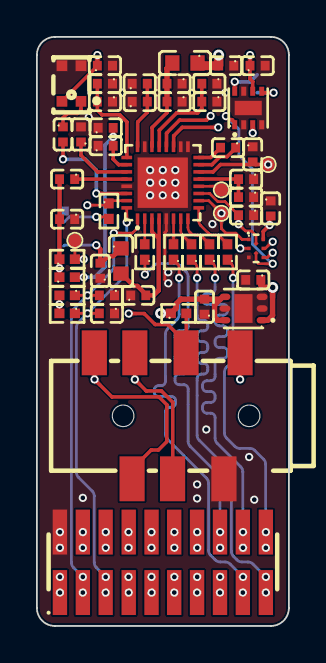
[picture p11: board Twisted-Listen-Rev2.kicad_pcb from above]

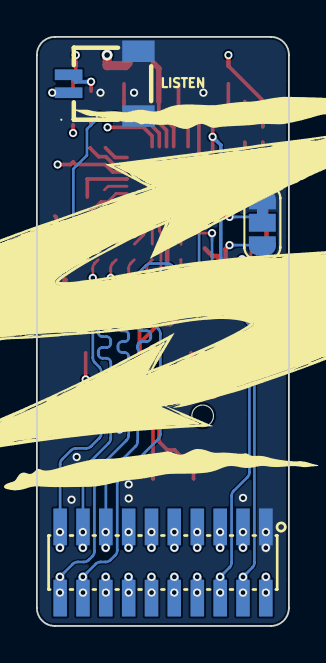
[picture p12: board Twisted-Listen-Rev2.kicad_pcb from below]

Board: 4 copper layers, 14.0 x 32.7 mm, 56 parts (3 on the bottom side), 50 nets.

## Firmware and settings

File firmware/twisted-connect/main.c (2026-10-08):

#include "ch32fun.h"
#include <stdio.h>

// use defines to make more meaningful names for our GPIO pins
#define PIN_1 PA4
#define PIN_K PA5
#define PIN_BOB PA8
#define PIN_KEVIN PA9

int main()
{
	SystemInit();

	funGpioInitAll(); // no-op on ch5xx

	funPinMode( PIN_1,     GPIO_CFGLR_OUT_10Mhz_PP ); // Set PIN_1 to output
	funPinMode( PIN_K,     GPIO_CFGLR_OUT_10Mhz_PP ); // Set PIN_K to output
	funPinMode( PIN_BOB,   GPIO_CFGLR_OUT_10Mhz_PP ); // Set PIN_BOB to output
	funPinMode( PIN_KEVIN, GPIO_CFGLR_OUT_10Mhz_PP ); // Set PIN_KEVIN to output


	while(1)
	{
		funDigitalWrite( PIN_1,     FUN_HIGH ); // Turn on PIN_1
		funDigitalWrite( PIN_K,     FUN_HIGH ); // Turn on PIN_K
		funDigitalWrite( PIN_BOB,   FUN_HIGH ); // Turn on PIN_BOB
		funDigitalWrite( PIN_KEVIN, FUN_HIGH ); // Turn on PIN_KEVIN
		Delay_Ms( 250 );
		funDigitalWrite( PIN_1,     FUN_LOW );  // Turn off PIN_1
		funDigitalWrite( PIN_K,     FUN_LOW );  // Turn off PIN_K
		funDigitalWrite( PIN_BOB,   FUN_LOW );  // Turn off PIN_BOB
		funDigitalWrite( PIN_KEVIN, FUN_LOW );  // Turn off PIN_KEVIN
		Delay_Ms( 250 );
	}
}

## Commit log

2026-09-29 chore: cleanup schematics and PCBs polishing (no logic changes)
    [Twisted-Listen-Rev2.kicad_pcb, Twisted-Listen-Rev2.kicad_sch, Twisted.kicad_pcb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]
2026-10-08 feat: upload Twisted Connect
    [Twisted-Connect.kicad_pcb, Twisted-Connect.kicad_sch, bom.csv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]
